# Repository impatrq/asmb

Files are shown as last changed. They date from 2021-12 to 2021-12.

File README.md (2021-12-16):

# Automatic Sanitary Modular Booth - ASMB

## ¿Que es ASMB?

ASMB es una cabina modular de desinfección automatica. El fin de esta es asegurar que un usuario se desinfecte antes de entrar en un espacio establecido, ademas de registrar su asistencia, temperatura y uso de barbijo.
Para explicación de funcionamiento en detalle, consultar el [Manual de Usuario](https://github.com/impatrq/asmb/blob/main/Docs/Carpeta%20técnica.docx)

<br>

## ¿Cuales son las bases ASMB?

- Integración: ASMB tambien cuenta con su propio sistema de registro de usuarios y estado de sensores. 

- Modularidad: Al momento de pedir sus cabinas se puede optar por cada sensor en el sistema

- Automatica: No requiere de intervención de un tercero para su utilización

<br>

## Indice

- [Documentos](https://github.com/impatrq/asmb/tree/main/Docs)

- [Historias de usuario](https://github.com/impatrq/asmb/tree/main/Historias%20de%20Usuario)

- [Live](https://github.com/impatrq/asmb/tree/main/Live)

- [Recursos](https://github.com/impatrq/asmb/tree/main/Recursos)

- [Server](https://github.com/impatrq/asmb/tree/main/Server)

## Reconocimientos
<b>2do puesto en prototipos II en Las olimpiadas nacionales ONIET</b>

<br>

## Desarollo

Juan I. Casareski: Software

Marco F. Cuccaro: Electronica

Iván Torres: Modelos

Agustín Murgia: Estructura

<br>

## Contacto

Juan I. Casareski: [juani.casareski@gmail.com](mailto:juani.casareski@gmail.com)

Marco F. Cuccaro: [cuccaromarco13@gmail.com](mailto:cuccaromarco13@gmail.com)

Iván Torres: [rantaproivo@gmail.com](mailto:rantaproivo@gmail.com)

Agustín Murgia: [murgiaagustin@gmail.com](mailto:murgiaagustin@gmail.com)

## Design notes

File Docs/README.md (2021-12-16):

||||
| :- | :-: | -: |

**Automatic Sanitary Modular Booth**



**Integrantes:**

**Casareski, Juan I.**

**Cuccaro, Marco F.**

**Murgia, Agustín N.**

**Torres, Iván B.**

**Índice:**

1. **Introducción**
   1. ** 	Objetivo del proyecto
   1. ` 	`Descripción general
   1. ` 	`Uso deseado
   1. ` 	`Diagrama en bloques
   1. ` 	`Diagrama de Gantt

2. **Componentes**
   1. ** 	Raspberry pi 4b
   1. ` 	`Sensor de temperatura infrarrojo MLX90614
   1. ` 	`Lector de tarjetas RFID RC522
   1. ` 	`Sensor de proximidad Fc-51
   1. ` 	`Sensores de reflexión E18 D80nk
   1. ` 	`Cámara USB
   1. ` 	`Shift Register 74HC595
   1. ` 	`Bomba de agua Bt30
   1. ` 	`Fuente genérica de computadora 500W

3. **Software**
   1. ** 	Clase general
   1. ` 	`Sensor de temperatura
   1. Detección facial
      1. ` 	`Detector de puntos faciales
      1. ` 	`Detector de barbijos
   1. `   	`Lector de tarjetas RFID RC522
   1. ` 	`Registro de empleados
   1. ` 	`Registro de clientes
   1. ` 	`Cartel de funcionamiento
   1. ` 	`Dispensador de alcohol en gel
   1. ` 	`Ingreso y egreso
   1. Panel de estado
   1. Funciones de día y hora

4. **Esquemáticos y PBC's**
   1. ** 	Motherboard
   1. ` 	`Panel de estado
   1. ` 	`Level shifters (Sensores de proximidad)
   1. ` 	`Adaptador RC522

5. **Modelos 3D**
   1. ` 	`Cabina completa
   1. ` 	`Soporte de la cámara
   1. ` 	`Carcasa del lector de tarjetas
   1. ` 	`Carcasa del sensor de temperatura
   1. ` 	`Dispensador de alcohol en gel

6. **Recursos**

   1. **Introducción**

1.1. **Objetivo del proyecto**

Este proyecto fue diseñado para la desinfección integral de un peatón/empleado. También cuenta con sensando de temperatura, reconocimiento facial, registro de asistencia y un indicador de funcionamiento para cada sensor. Este cuenta con un enfoque a la modularidad del sistema.

1.2 **Descripción general**

El proyecto ASMB fue construido desde la base por alumnos de la EEST N7 TRQ, cuya estructura hecha integralmente de materiales provisto en la escuela.

1.3 **Uso deseado**

La cabina está diseñada para ser montada en un espacio abierto antes del acceso a un establecimiento, donde el usuario se tomará la temperatura antes de entrar a la cabina, en caso de que sea un empleado deberá también poner su tarjeta de identificación. Una vez dentro de la cabina se le detectará la cara al usuario para determinar si tiene los ojos y boca cerrados (u opcionalmente el uso de un barbijo), una vez confirmado esto se desinfectará al usuario y este mismo podrá salir de las misma, sin antes desinfectarse las manos con el dispensador de alcohol en gel. Este mismo ingreso será guardado en una base de datos local junto a el horario de entrada, temperatura y el supuesto horario de entrada.

1.4 **Diagrama en bloques**





1.5 **Diagrama de Gantt**



2. **Componentes**

2.1 **Raspberry pi 4B**

Este microprocesador fue seleccionado ya que requeríamos de una potencia considerable para poder ejecutar los scripts de detección facial. Todas las conexiones que requieren de alguna lógica se conectan a este mediante la motherboard.

2.2 **Sensor de temperatura infrarrojo MLX90614**

El MLX90614 es un sensor de temperatura sin contacto. Este sensor tiene un error de aproximadamente 0.14 C y un rango de medición de –20 C a 120 C. Este comunica la temperatura leída al microprocesador mediante un protocolo serial I²C.

2.3 **Lector de tarjetas RFID RC522**

Este módulo lee las tarjetas RFID las cuales incluyen dos valores: id y texto. 

2.4 **Sensor de proximidad Fc-51**

Este sensor detecta objetos en su rango de visión de 15 grados, a un máximo de 30cm. Es usado en el dispensador de alcohol sin contacto.

2.5 **Sensor de reflexión E18 D80nk**

Su funcionamiento es muy similar a el sensor de proximidad (De hecho, usan el mismo concepto para cumplir su función) con la diferencia de que son más sensibles y, por lo tanto, su rango de medición máximo aumenta de 30cm a 80cm.

2.6 **Cámara USB**

La cámara seleccionada fue la sinovisión sn-u4 principalmente a que fue probada con el microprocesador al cual se le pudo instalar los drivers de la misma. A esto se le suma que cuenta con los requerimientos necesarios para nuestra aplicación.

2.7 **Shift register 74HC595**

El 74hc595 es un shift register de 8 bits, esta cuadra con nuestro uso ya que no requerimos de una alta corriente en la salida. 

2.8 **Bomba de agua Bt30**

La bomba tiene una potencia de 30W, funciona en 220W@50Hz. La mima tiene un caudal de 48L/h y una presión de 3bar, la presión de la cual requeríamos es de 2.5bar, pero tenemos un excedente principalmente debido a que el sistema puede tener perdidas.

2.9 **Fuente genérica de computadora 500W**

La fuente seleccionada fue una de computadora para mantener la simplicidad del sistema. Esta fuente se conecta a la motherboard (Ver sección 4.1.) mediante un conector molex de 24 pines.

3. **Software**

3.1 **Clase general**

Esta fue ideada para la fácil reimplementación de los pines del sistema una situación en la que esto sea de utilidad seria, por ejemplo, El reemplazo de una RP3 por otro microprocesador por una RP4 (Situación la cual se dio en el mismo proyecto). Todos los archivos están disponibles en el repositorio (Ver sección 6). 

3.2 **Sensor de temperatura**

Este sería el uso deseado de la clase <Temperatura>



El método <readTemp> devuelve dos valores, el primero hace referencia a si la persona está habilitada a entrar, siendo 'True' si se encuentra en el rango de temperatura permitido y 'False' si no se encuentra en dicho rango, el segundo valor es la temperatura leída.

3.3 **Detección Facial**

Esta parte cuenta con dos variaciones, la primera donde se detecta que los ojos y la boca estén cerrados y el segundo donde se detecta el uso de un barbijo.

3.4 **Detector de puntos faciales**	

Este se encarga de detectar el hecho de que el usuario tenga los ojos y boca cerrados por al menos 3 segundos para comenzar a desinfectar.



Cabe aclarar que al constructor <FaceDetection> se le pasa un argumento para seleccionar el modo de detección facial (En este caso 'eyes&Mouth')

3.5 **Detector de barbijos**

Este detecta de detectar el uso de un barbijo para comenzar el proceso de desinfección



La única diferencia con el ejemplo anterior es la key distinta del constructor <FaceDetection>.

3.6 **Lector de tarjetas RFID RC522**

Este lector lee los dos datos dentro de la tarjeta, primero la id y segundo el text. El ejemplo siguiente lee estos dos anteriormente nombrados.



3.6 **Registro de empleados**

El registro de empleados se implementó mediante una función la cual pide con parámetros la id de este trabajador y su temperatura, esta misma función se encarga de conseguir la hora y día actual y de guardarlo todos los datos en una base de datos local.



En este ejemplo primero se le toma la temperatura al empleado, después su tarjeta de identificación y se guarda en la base de datos. Cabe aclarar que tanto el id de la tarjeta como el estado del sensor de temperatura no se utilizan en este ejemplo por lo que se les reemplazó por una '\_'.

3.7 **Registro de clientes**

El registro de empleados es una versión simplificada del registro de empleados, ya que un peatón normal no cuenta con una tarjeta de identificación por lo que no se ve sometido a un paso extra.



3.8 **Cartel de funcionamiento**

El fin de este cartel es de indicar cuando la cabina está fuera de funcionamiento o cuando está ocupada. 



Este ejemplo alterna el estado del panel de funcionamiento cada .5 segundos. Cabe aclarar que en la línea 5 el constructor <Pin> requiere 3 argumentos: el primero es el número de pin, el segundo es su modo de funcionamiento y el tercero es el estado inicial de dicho pin.

3.9 **Dispensador de alcohol en gel**

El dispensador de alcohol tiene la particularidad que tiene que funcionar de forma independiente al resto del sistema. Por esto utilizamos el módulo <threading>. Ignorando ese hecho el sistema lee un pin donde se conecta el sensor de proximidad para dispensar el alcohol.



Como se puede observar en el ejemplo primero se crea los objetos para los pines del sensor de proximidad y del motor, los cuales se pasan como argumento a el constructor <DispenserAlcohol>, constructor el cual toma 3 argumentos, siendo el tercero el tiempo total de activación del motor. Finalmente se crea un hilo el cual ejecuta el método principal del dispensador de alcohol.

3.10 **Ingreso y egreso**

La sección de ingreso y egreso se refiere a los sensores de proximidad que se encargan de lo anterior nombrado. La lógica detrás de este proceso es esperar hasta que algo corte el haz del sensor y el microprocesador lo lea.



En este ejemplo primero se definen los pines de los sensores de proximidad y de un led de debug (Que indica que una persona está en la cabina) y estos pines se dan como argumentos al constructor <IO>. Finalmente se verifica hasta que alguien pase por enfrente del sensor de proximidad de la entrada y posteriormente con el de la salida. 

3.11 **Panel de estado**

El estado de los sensores se manda mediante una comunicación serial sincrónica hacia un shift register (Ver sección 4.2.). El microprocesador comunica 1 byte de datos, en el cual cada bit indica si x sensor tiene una falla.



En el ejemplo anterior primero se crea el objeto del cartel de funcionamiento (Ver sección 3.7.), posteriormente se definen los pines del clock de los registros del shift register, el pin de datos y el pin de clock de la salida del shift register (Sh\_cp, ds y St\_cp, respectivamente). Después se definen los pines de entrada de los sensores de efecto hall. Finalmente crea el objeto del panel de estado con base el constructor <PanelEstado> y se lee el estado de todos los sensores, para posteriormente mostrarlos en el panel de estado.

3.12 **Funciones de día y hora**

Esta sección hace referencia a un set de funciones escritas para estandarizar la obtención de hora/día/día de la semana dentro del proyecto. Estas utilizan el módulo <datetime> para su funcionalidad.



4 **Esquemáticos y PBC's**  

   4.1 **Motherboard**

El fin este circuito es de conectar todos los dispositivos periféricos al microprocesador. 





4.2 **Panel de estado**

Este panel recibe el estado de todos los sensores desde el microprocesador y lo indica en 8 LED's. Esta señal se recibe como un paquete de 1 byte, el cual indica este en 8 LED's distintos mediante un 74HC595, a la salida de cada registro del anterior nombrad hay un BC337 ya que la corriente máxima soportada por el shift register es facilmente excedida por un par de LED's prendidos.





4.3 **Level shifters**

Este circuito es el encargado de adaptar los niveles lógicos de los sensores de efecto hall y de los sensores de proximidad y reflexión. Los anteriores nombrados usan 5v para representar un 1 lógico, este circuito es el encargado de convertir estos 5v a 3v3, mediante un diodo Zener.





4.4 **Adaptador RC522**

Este circuito tiene la única y sola función de adaptar la tira de pines del RC522 a unas borneras para su fácil conexión. 





1. **Modelos 3D**

Todos los modelos están disponibles en el repositorio del proyecto (Ver sección 6), en el directorio src>Recursos>Modelos

1. **Cabina completa**



1. **Soporte de la cámara**



1. **Carcasa del lector de tarjetas**



1. **Carcasa del sensor de temperatura**



1. **Dispensador de alcohol en gel**



6. **Recursos**

[**Modelos 3D**](https://github.com/impatrq/asmb/tree/main/Recursos/Modelos)

[**Circuitos y PCB's**](https://github.com/impatrq/asmb/tree/main/Recursos/Circuitos)

[**Script**](https://github.com/impatrq/asmb/tree/main/Live/src/Libs)

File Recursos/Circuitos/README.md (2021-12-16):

<font size="8">CIRCUITOS:

<font size="3">
 Estos son los circuitos que van a encontrar en esta seccion:

<font size="4">

[Circuito del dispenser:](https://github.com/impatrq/asmb/blob/main/Recursos/Circuitos/Dispenser%20de%20alcohol/Dispenser%20de%20alcohol%20en%20gel.pdsprj)



[Circuito del lector de tarjetas:](https://github.com/impatrq/asmb/blob/main/Recursos/Circuitos/Lector%20de%20tarjetas/Lector%20de%20tarjetas.pdsprj)



[Circuito de la mother:](https://github.com/impatrq/asmb/blob/main/Recursos/Circuitos/Mother/Mother.pdsprj)



[Circuito del panel de estado:](https://github.com/impatrq/asmb/blob/main/Recursos/Circuitos/Panel%20de%20estado/Panel%20de%20estado.pdsprj)



[Circuito de los sensores de proximidad:](https://github.com/impatrq/asmb/blob/main/Recursos/Circuitos/Proximity%20sensors/Level%20adapter.pdsprj)



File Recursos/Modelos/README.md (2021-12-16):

[Modelo de la cabina:](https://github.com/impatrq/asmb/blob/main/Recursos/Modelos/Cabina%20general/Modelo%20Cabina.dwg)



[Modelo del cartel de ocupado:](https://github.com/impatrq/asmb/blob/main/Recursos/Modelos/Cartel%20ocupado/Cartel%20Ocupado.dwg)



[Dispenser de alcohol:](https://github.com/impatrq/asmb/blob/main/Recursos/Modelos/Dispenser%20de%20alcohol%20en%20gel/Dispenser%20de%20alcohol%20en%20gel.dwg)



[Lector de tarjetas:](https://github.com/impatrq/asmb/blob/main/Recursos/Modelos/Dispenser%20de%20alcohol%20en%20gel/Dispenser%20de%20alcohol%20en%20gel.dwg)



[Sensor de temperatura:](https://github.com/impatrq/asmb/blob/main/Recursos/Modelos/Sensor%20de%20temperatura/Sensor%20de%20temperatura.dwg)



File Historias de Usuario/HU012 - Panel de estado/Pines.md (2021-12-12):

# Pines

* **Lector de tarjetas**        [GPIO19, GPIO16, GPIO20, GPIO21] **SPI1**
* **Sensor de temperatura**     [GPIO2, GPIO3] **I²C1** 
* **Sensores de obstaculos**    [GPIO18, GPIO23, GPIO24, GPIO25, GPIO8, GPIO7]
* **Buzzer**                    [GPIO12]
* **Pin testeo LEDS**           [GPIO4]
* **Pines del panel de estado** [GPIO17, GPIO27, GPIO22]

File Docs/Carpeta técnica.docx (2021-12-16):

Automatic Sanitary Modular Booth

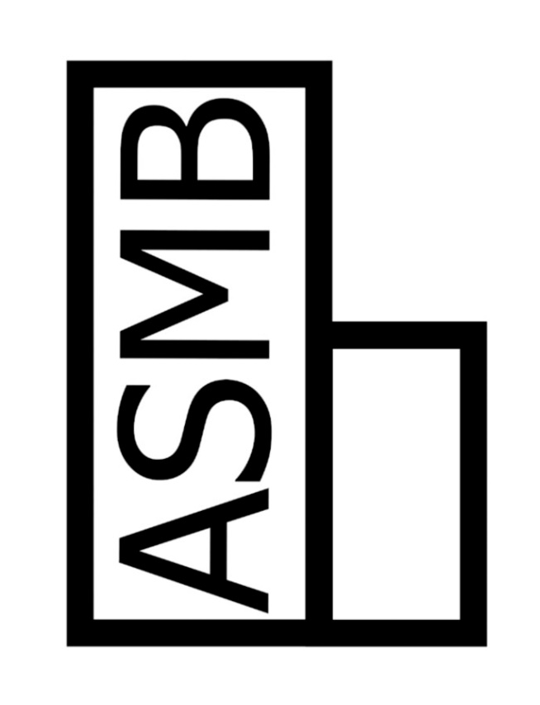
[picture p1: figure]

Integrantes:

Casareski, Juan I.

Cuccaro, Marco F.

Murgia, Agustín N.

Torres, Iván B.

Índice:

1. Introducción
  1.1. Objetivo del proyecto
  1.2. Descripción general
  1.3. Uso deseado
  1.4. Diagrama en bloques
  1.5. Diagrama de Gantt
2. Componentes
  2.1. Raspberry pi 4b
  2.2. Sensor de temperatura infrarrojo MLX90614
  2.3. Lector de tarjetas RFID RC522
  2.4. Sensor de proximidad Fc-51
  2.5. Sensores de reflexión E18 D80nk
  2.6. Cámara USB
  2.7. Shift Register 74HC595
  2.8. Bomba de agua Bt30
  2.9. Fuente genérica de computadora 500W
3. Software
  3.1. Clase general
  3.2. Sensor de temperatura
  3.3. Detección facial
    3.3.1. Detector de puntos faciales
    3.3.2. Detector de barbijos
  3.4. Lector de tarjetas RFID RC522
  3.5. Registro de empleados
  3.6. Registro de clientes
  3.7. Cartel de funcionamiento
  3.8. Dispensador de alcohol en gel
  3.9. Ingreso y egreso
  3.10. Panel de estado
  3.11. Funciones de día y hora
4. Esquemáticos y PBC's
  4.1. Motherboard
  4.2. Panel de estado
  4.3. Level shifters (Sensores de proximidad)
  4.4. Adaptador RC522
5. Modelos 3D
  5.1. Cabina completa
  5.2. Soporte de la cámara
  5.3. Carcasa del lector de tarjetas
  5.4. Carcasa del sensor de temperatura
  5.5. Dispensador de alcohol en gel
6. Recursos
1. Introducción
  1.1. Objetivo del proyecto

Este proyecto fue diseñado para la desinfección integral de un peatón/empleado. También cuenta con sensando de temperatura, reconocimiento facial, registro de asistencia y un indicador de funcionamiento para cada sensor. Este cuenta con un enfoque a la modularidad del sistema.

  1.2. Descripción general

El proyecto ASMB fue construido desde la base por alumnos de la EEST N7 TRQ, cuya estructura hecha integralmente de materiales provisto en la escuela.

  1.3. Uso deseado

La cabina está diseñada para ser montada en un espacio abierto antes del acceso a un establecimiento, donde el usuario se tomará la temperatura antes de entrar a la cabina, en caso de que sea un empleado deberá también poner su tarjeta de identificación. Una vez dentro de la cabina se le detectará la cara al usuario para determinar si tiene los ojos y boca cerrados (u opcionalmente el uso de un barbijo), una vez confirmado esto se desinfectará al usuario y este mismo podrá salir de las misma, sin antes desinfectarse las manos con el dispensador de alcohol en gel. Este mismo ingreso será guardado en una base de datos local junto a el horario de entrada, temperatura y el supuesto horario de entrada.

  1.4. Diagrama en bloques

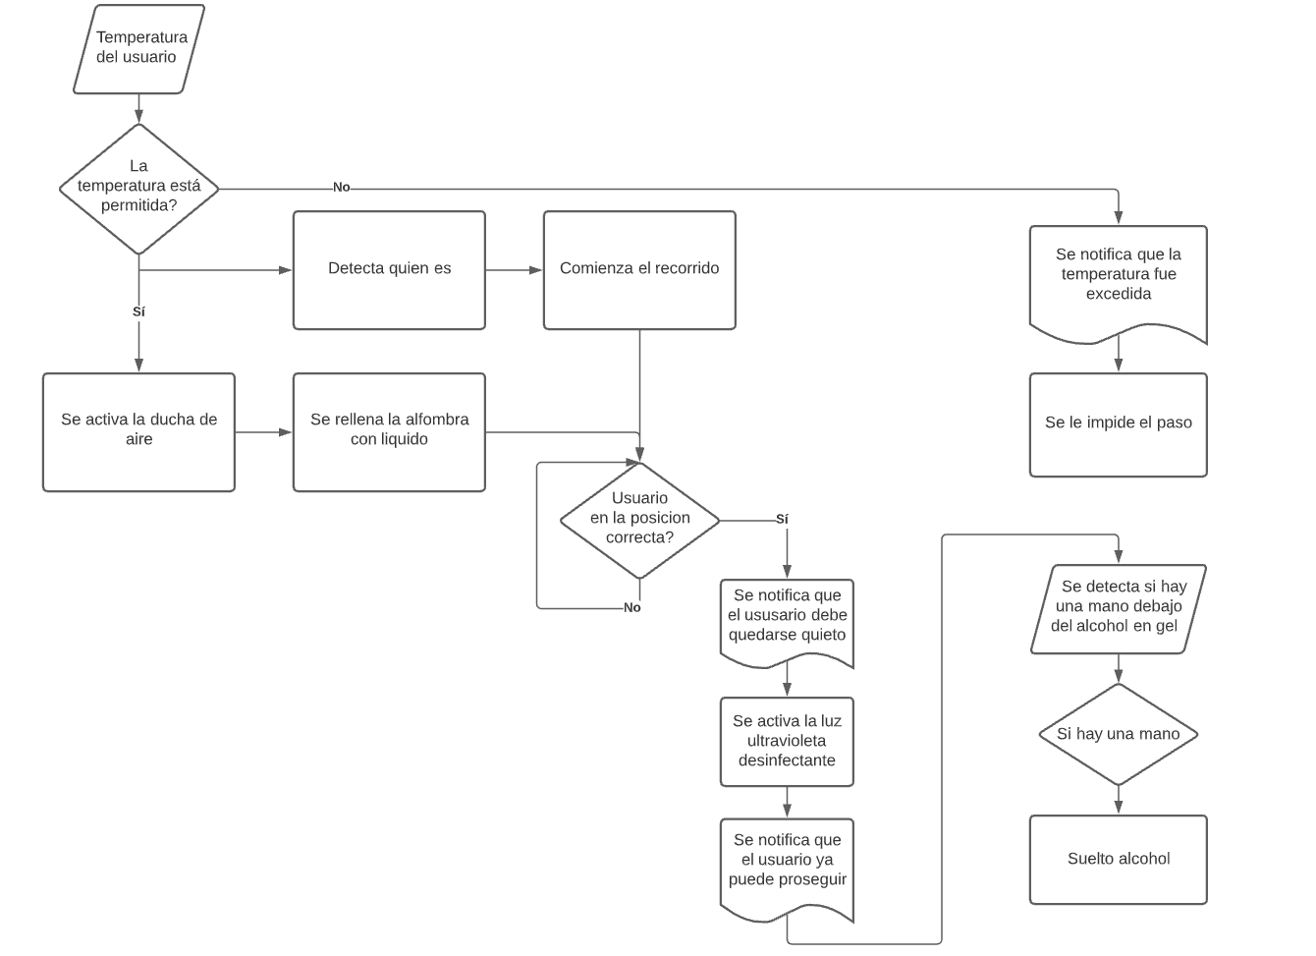
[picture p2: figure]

  1.5. Diagrama de Gantt

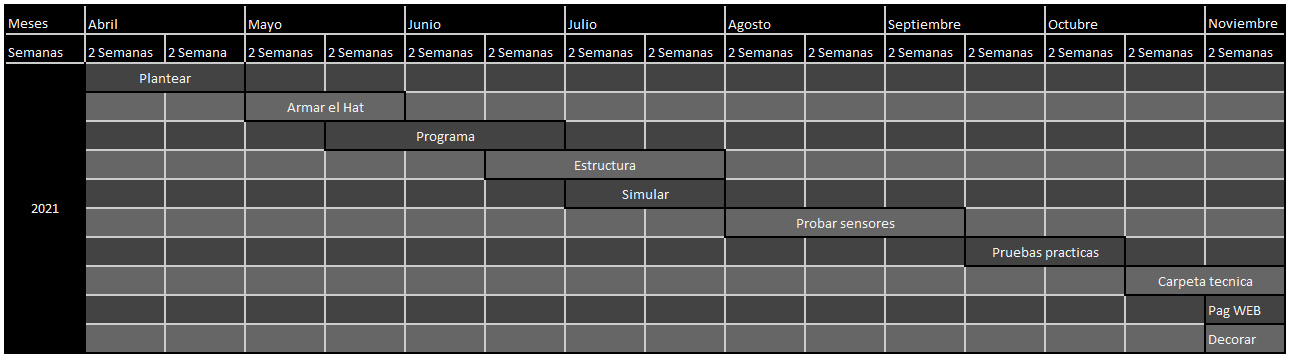
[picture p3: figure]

2. Componentes
  2.1. Raspberry pi 4B

Este microprocesador fue seleccionado ya que requeríamos de una potencia considerable para poder ejecutar los scripts de detección facial. Todas las conexiones que requieren de alguna lógica se conectan a este mediante la motherboard.

  2.2. Sensor de temperatura infrarrojo MLX90614

El MLX90614 es un sensor de temperatura sin contacto. Este sensor tiene un error de aproximadamente 0.14 C y un rango de medición de –20 C a 120 C. Este comunica la temperatura leída al microprocesador mediante un protocolo serial I²C.

  2.3. Lector de tarjetas RFID RC522

Este módulo lee las tarjetas RFID las cuales incluyen dos valores: id y texto.

  2.4. Sensor de proximidad Fc-51

Este sensor detecta objetos en su rango de visión de 15 grados, a un máximo de 30cm. Es usado en el dispensador de alcohol sin contacto.

  2.5. Sensor de reflexión E18 D80nk

Su funcionamiento es muy similar a el sensor de proximidad (De hecho, usan el mismo concepto para cumplir su función) con la diferencia de que son más sensibles y, por lo tanto, su rango de medición máximo aumenta de 30cm a 80cm.

  2.6. Cámara USB

La cámara seleccionada fue la sinovisión sn-u4 principalmente a que fue probada con el microprocesador al cual se le pudo instalar los drivers de la misma. A esto se le suma que cuenta con los requerimientos necesarios para nuestra aplicación.

  2.7. Shift register 74HC595

El 74hc595 es un shift register de 8 bits, esta cuadra con nuestro uso ya que no requerimos de una alta corriente en la salida.

  2.8. Bomba de agua Bt30

La bomba tiene una potencia de 30W, funciona en 220W@50Hz. La mima tiene un caudal de 48L/h y una presión de 3bar, la presión de la cual requeríamos es de 2.5bar, pero tenemos un excedente principalmente debido a que el sistema puede tener perdidas.

  2.9. Fuente genérica de computadora 500W

La fuente seleccionada fue una de computadora para mantener la simplicidad del sistema. Esta fuente se conecta a la motherboard (Ver sección 4.1.) mediante un conector molex de 24 pines.

3. Software
  3.1. Clase general

Esta fue ideada para la fácil reimplementación de los pines del sistema una situación en la que esto sea de utilidad seria, por ejemplo, El reemplazo de una RP3 por otro microprocesador por una RP4 (Situación la cual se dio en el mismo proyecto). Todos los archivos están disponibles en el repositorio (Ver sección 6).

  3.2. Sensor de temperatura

Este sería el uso deseado de la clase <Temperatura>

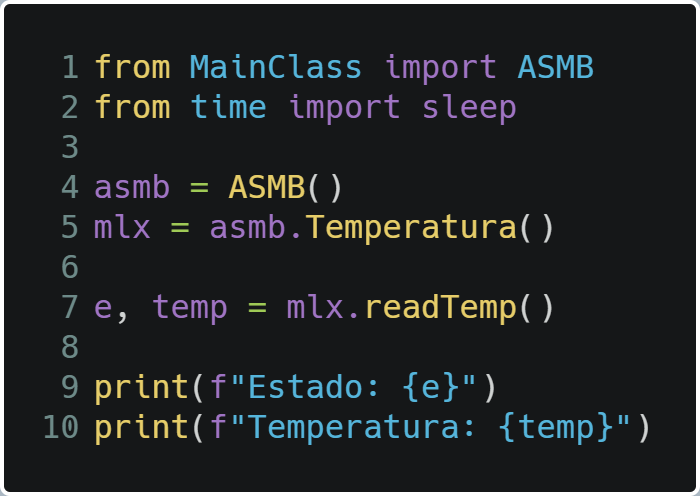
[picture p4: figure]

El método <readTemp> devuelve dos valores, el primero hace referencia a si la persona está habilitada a entrar, siendo 'True' si se encuentra en el rango de temperatura permitido y 'False' si no se encuentra en dicho rango, el segundo valor es la temperatura leída.

  3.3. Detección Facial

Esta parte cuenta con dos variaciones, la primera donde se detecta que los ojos y la boca estén cerrados y el segundo donde se detecta el uso de un barbijo.

    3.3. Detector de puntos faciales

Este se encarga de detectar el hecho de que el usuario tenga los ojos y boca cerrados por al menos 3 segundos para comenzar a desinfectar.

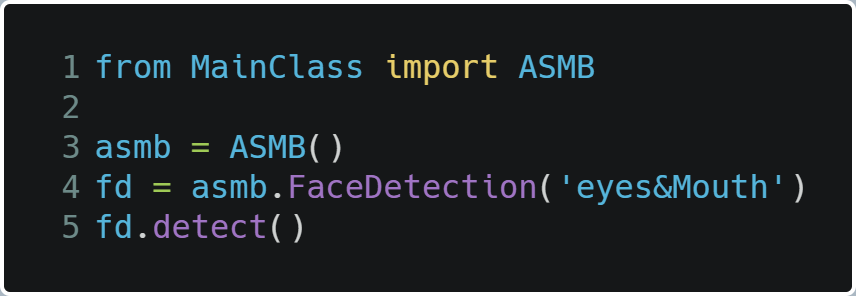
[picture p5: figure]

Cabe aclarar que al constructor <FaceDetection> se le pasa un argumento para seleccionar el modo de detección facial (En este caso 'eyes&Mouth')

    3.3. Detector de barbijos

Este detecta de detectar el uso de un barbijo para comenzar el proceso de desinfección

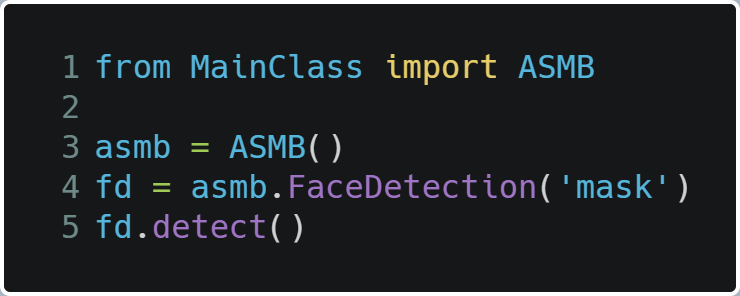
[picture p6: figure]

La única diferencia con el ejemplo anterior es la key distinta del constructor <FaceDetection>.

  3.4. Lector de tarjetas RFID RC522

Este lector lee los dos datos dentro de la tarjeta, primero la id y segundo el text. El ejemplo siguiente lee estos dos anteriormente nombrados.

  3.5. Registro de empleados

El registro de empleados se implementó mediante una función la cual pide con parámetros la id de este trabajador y su temperatura, esta misma función se encarga de conseguir la hora y día actual y de guardarlo todos los datos en una base de datos local.

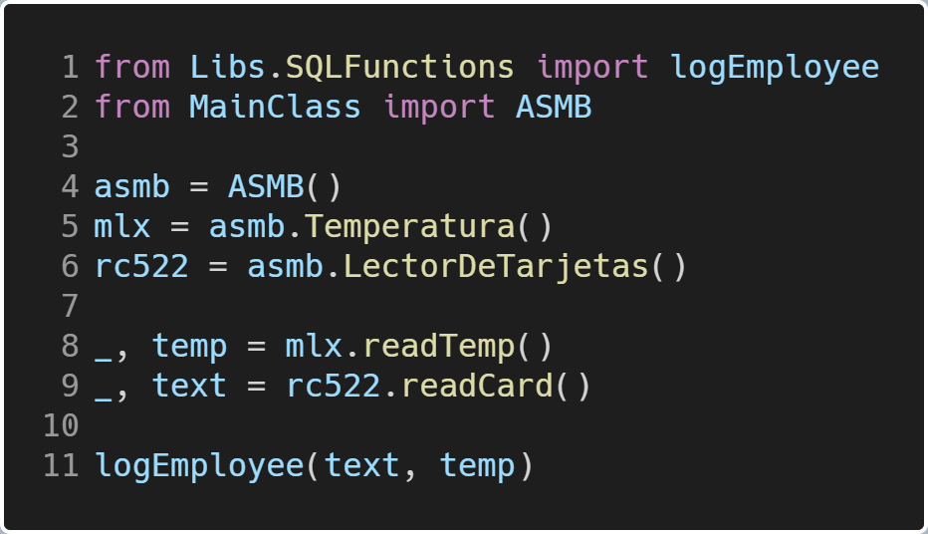
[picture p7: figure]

En este ejemplo primero se le toma la temperatura al empleado, después su tarjeta de identificación y se guarda en la base de datos. Cabe aclarar que tanto el id de la tarjeta como el estado del sensor de temperatura no se utilizan en este ejemplo por lo que se les reemplazó por una '_'.

  3.6. Registro de clientes

El registro de empleados es una versión simplificada del registro de empleados, ya que un peatón normal no cuenta con una tarjeta de identificación por lo que no se ve sometido a un paso extra.

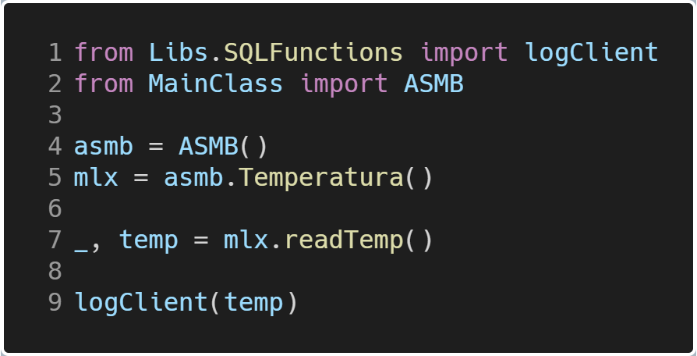
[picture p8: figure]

  3.7. Cartel de funcionamiento

El fin de este cartel es de indicar cuando la cabina está fuera de funcionamiento o cuando está ocupada.

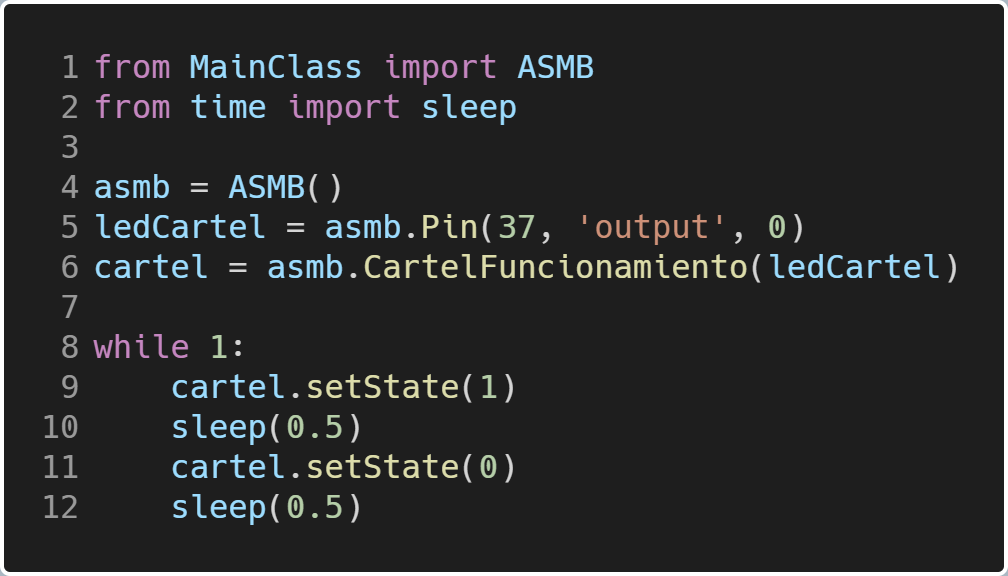
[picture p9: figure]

Este ejemplo alterna el estado del panel de funcionamiento cada .5 segundos. Cabe aclarar que en la línea 5 el constructor <Pin> requiere 3 argumentos: el primero es el número de pin, el segundo es su modo de funcionamiento y el tercero es el estado inicial de dicho pin.

  3.8. Dispensador de alcohol en gel

El dispensador de alcohol tiene la particularidad que tiene que funcionar de forma independiente al resto del sistema. Por esto utilizamos el módulo <threading>. Ignorando ese hecho el sistema lee un pin donde se conecta el sensor de proximidad para dispensar el alcohol.

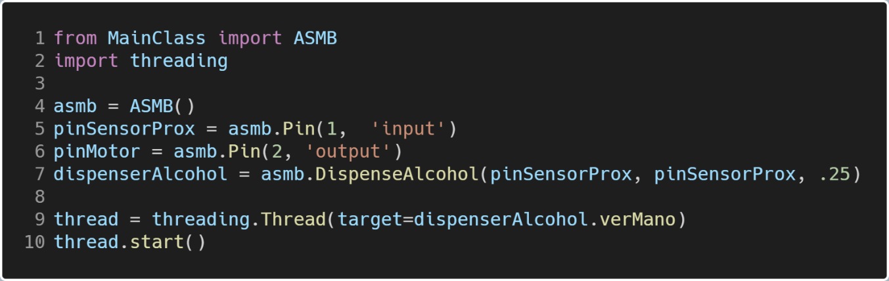
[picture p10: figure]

Como se puede observar en el ejemplo primero se crea los objetos para los pines del sensor de proximidad y del motor, los cuales se pasan como argumento a el constructor <DispenserAlcohol>, constructor el cual toma 3 argumentos, siendo el tercero el tiempo total de activación del motor. Finalmente se crea un hilo el cual ejecuta el método principal del dispensador de alcohol.

  3.9. Ingreso y egreso

La sección de ingreso y egreso se refiere a los sensores de proximidad que se encargan de lo anterior nombrado. La lógica detrás de este proceso es esperar hasta que algo corte el haz del sensor y el microprocesador lo lea.

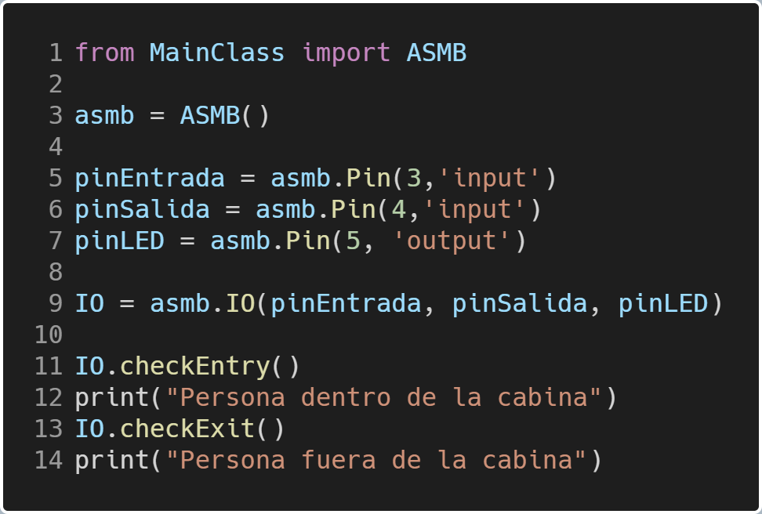
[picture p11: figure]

En este ejemplo primero se definen los pines de los sensores de proximidad y de un led de debug (Que indica que una persona está en la cabina) y estos pines se dan como argumentos al constructor <IO>. Finalmente se verifica hasta que alguien pase por enfrente del sensor de proximidad de la entrada y posteriormente con el de la salida.

  3.10. Panel de estado

El estado de los sensores se manda mediante una comunicación serial sincrónica hacia un shift register (Ver sección 4.2.). El microprocesador comunica 1 byte de datos, en el cual cada bit indica si x sensor tiene una falla.

En el ejemplo anterior primero se crea el objeto del cartel de funcionamiento (Ver sección 3.7.), posteriormente se definen los pines del clock de los registros del shift register, el pin de datos y el pin de clock de la salida del shift register (Sh_cp, ds y St_cp, respectivamente). Después se definen los pines de entrada de los sensores de efecto hall. Finalmente crea el objeto del panel de estado con base el constructor <PanelEstado> y se lee el estado de todos los sensores, para posteriormente mostrarlos en el panel de estado.

  3.11. Funciones de día y hora

Esta sección hace referencia a un set de funciones escritas para estandarizar la obtención de hora/día/día de la semana dentro del proyecto. Estas utilizan el módulo <datetime> para su funcionalidad.

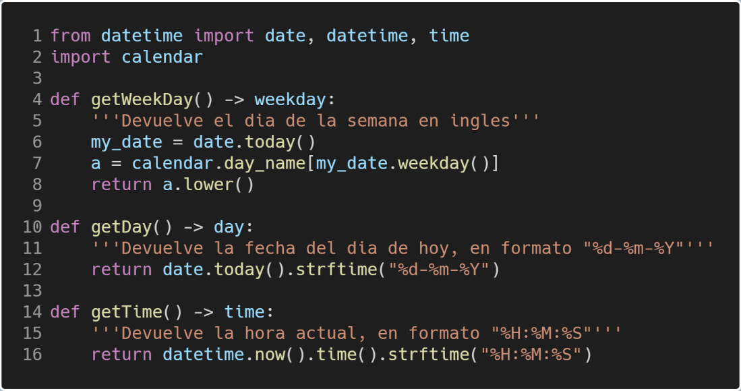
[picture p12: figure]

4. Esquemáticos y PBC's
  4.1. Motherboard

El fin este circuito es de conectar todos los dispositivos periféricos al microprocesador.

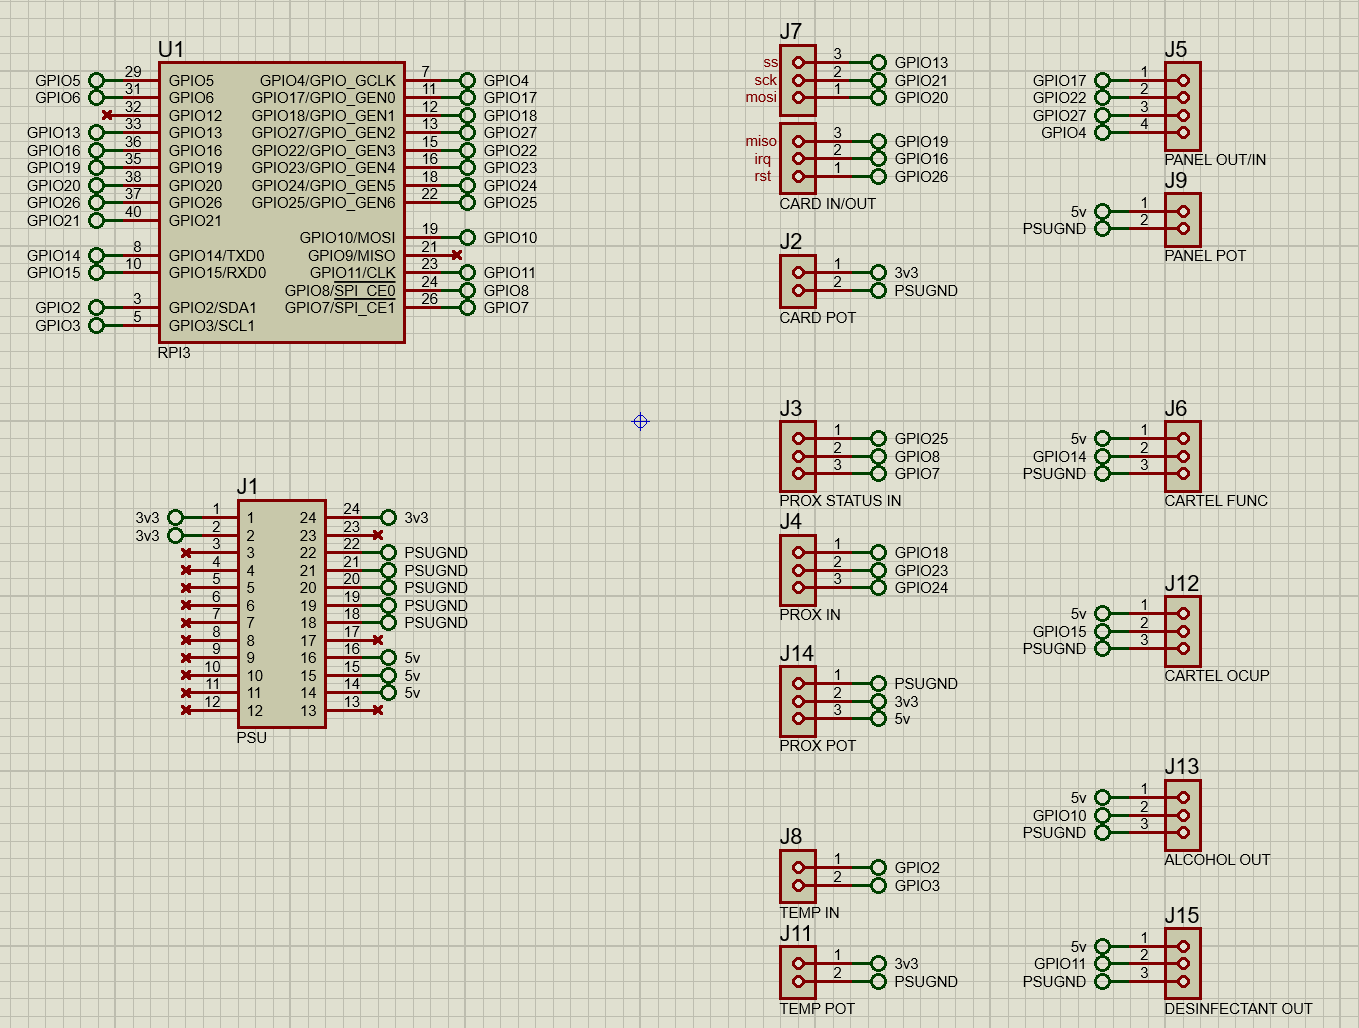
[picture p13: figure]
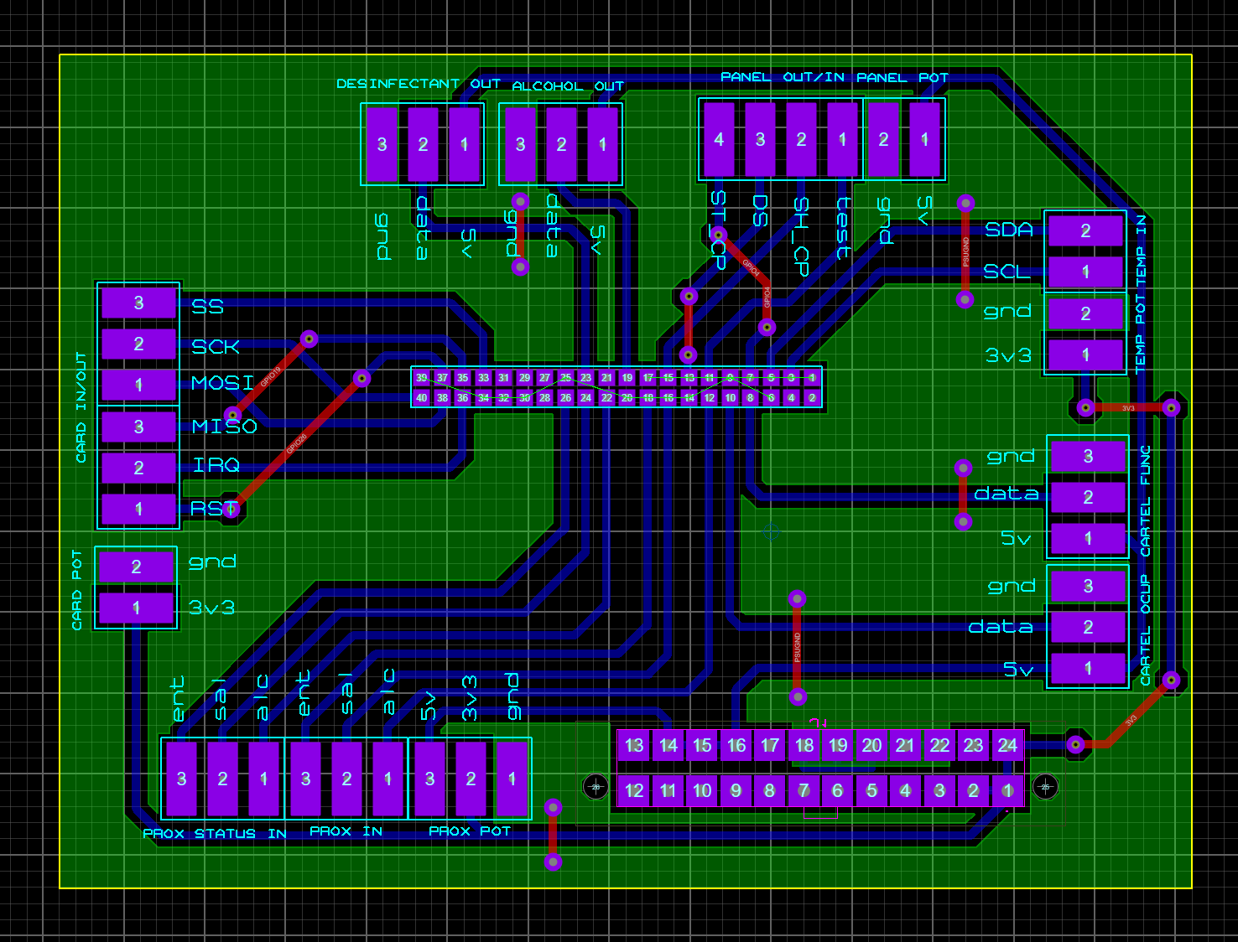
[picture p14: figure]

  4.2. Panel de estado

Este panel recibe el estado de todos los sensores desde el microprocesador y lo indica en 8 LED's. Esta señal se recibe como un paquete de 1 byte, el cual indica este en 8 LED's distintos mediante un 74HC595, a la salida de cada registro del anterior nombrad hay un BC337 ya que la corriente máxima soportada por el shift register es facilmente excedida por un par de LED's prendidos.

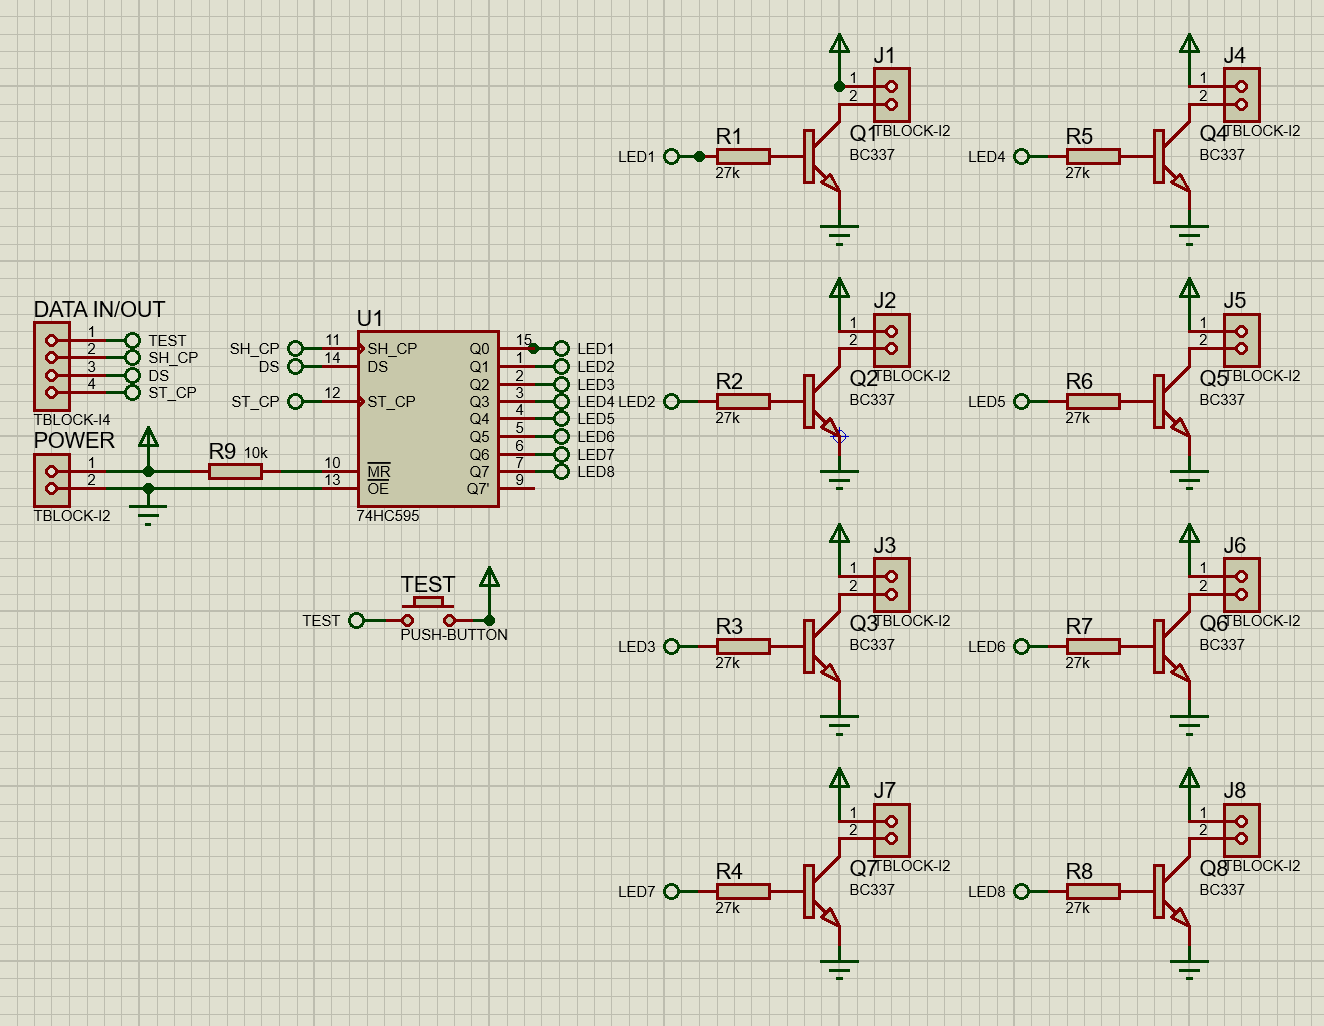
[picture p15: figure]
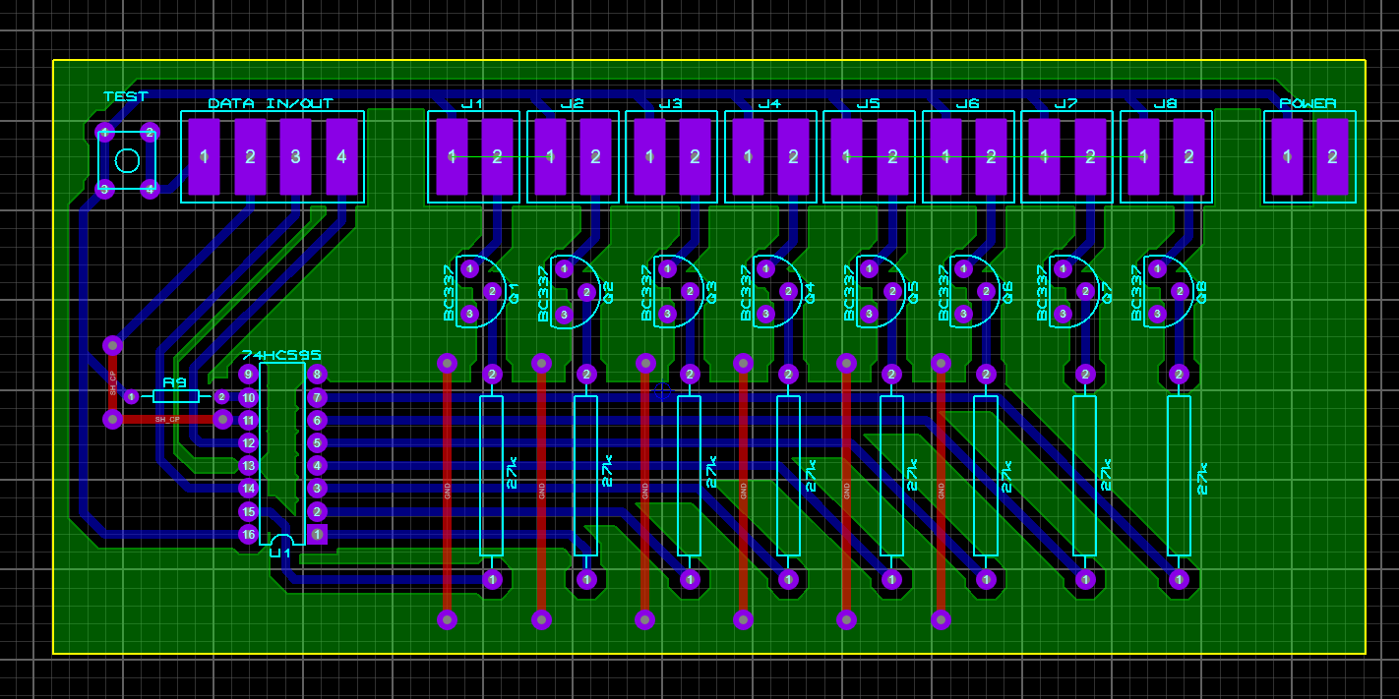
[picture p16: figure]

  4.3. Level shifters

Este circuito es el encargado de adaptar los niveles lógicos de los sensores de efecto hall y de los sensores de proximidad y reflexión. Los anteriores nombrados usan 5v para representar un 1 lógico, este circuito es el encargado de convertir estos 5v a 3v3, mediante un diodo Zener.

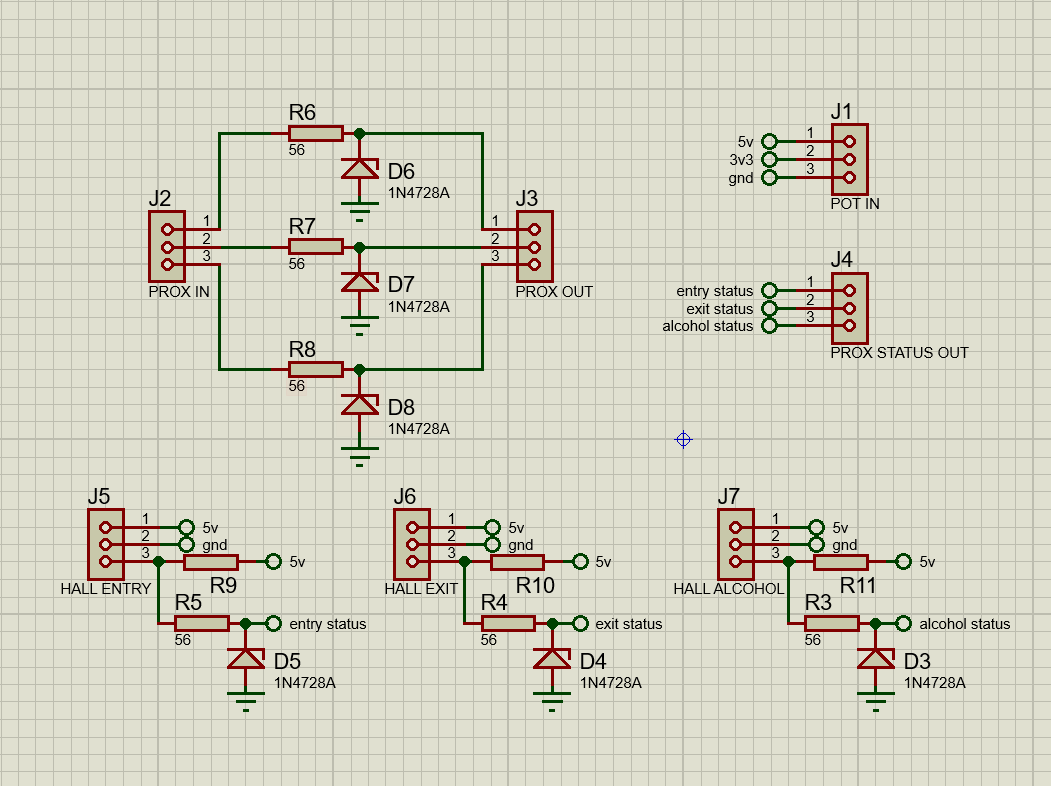
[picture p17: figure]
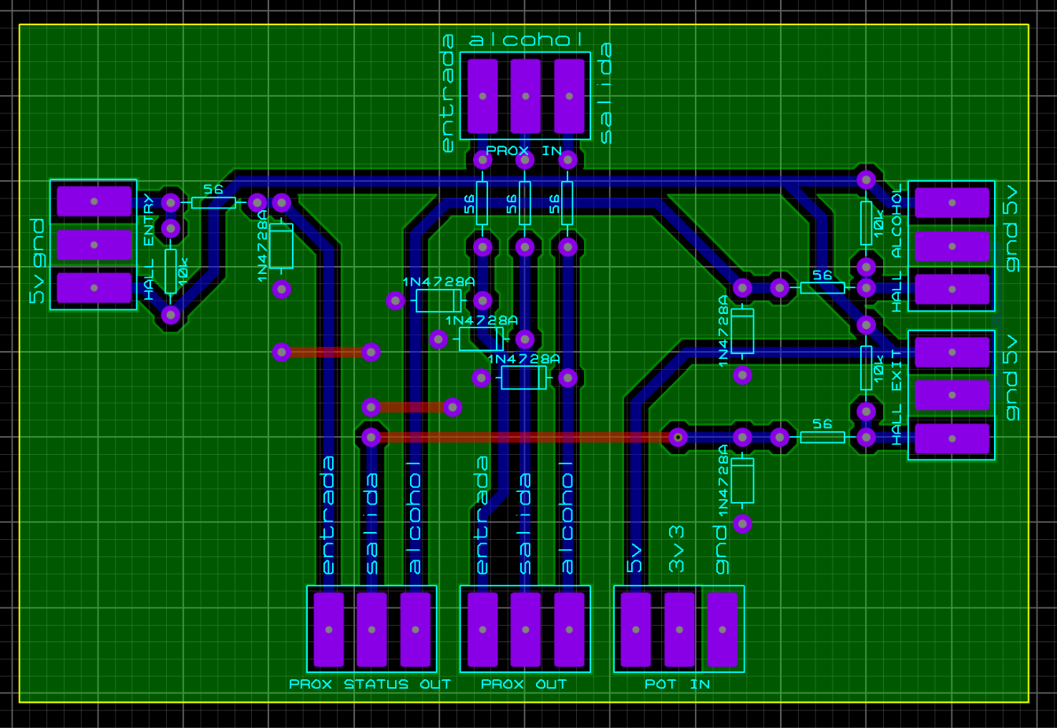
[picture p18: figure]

  4.4. Adaptador RC522

Este circuito tiene la única y sola función de adaptar la tira de pines del RC522 a unas borneras para su fácil conexión.

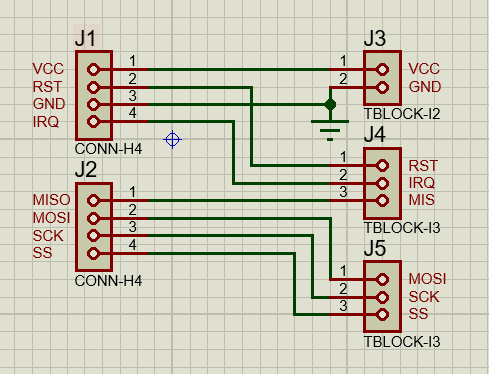
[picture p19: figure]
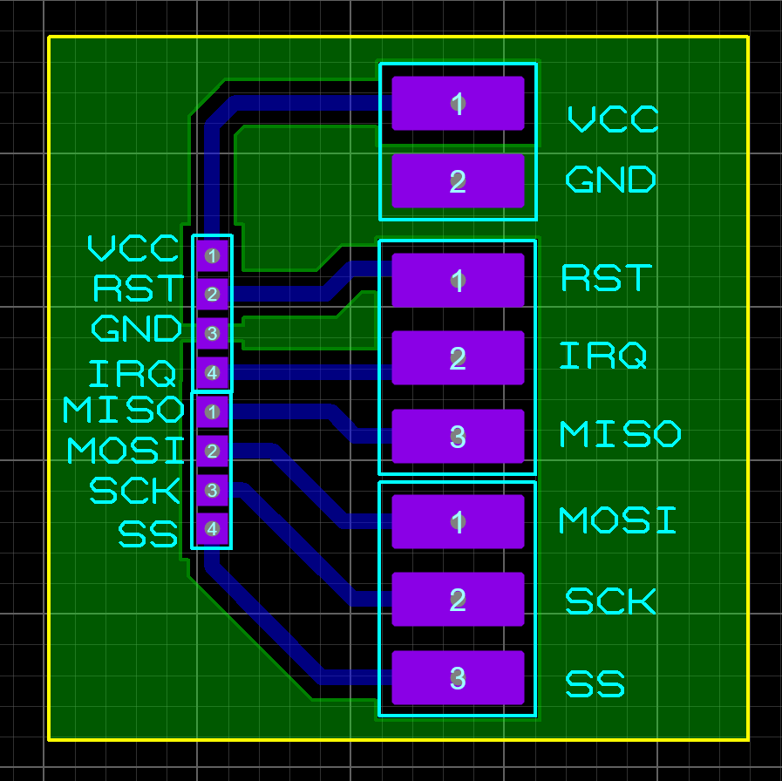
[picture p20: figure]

5. Modelos 3D

Todos los modelos están disponibles en el repositorio del proyecto (Ver sección 6), en el directorio src>Recursos>Modelos

  5.1. Cabina completa

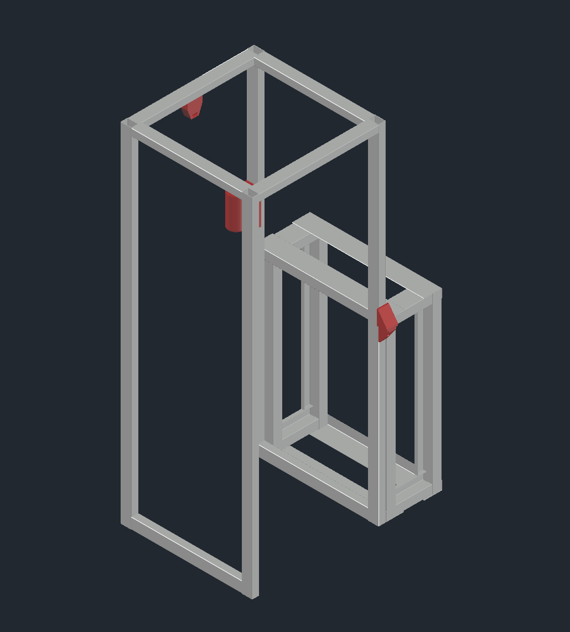
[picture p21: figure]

  5.2. Soporte de la cámara

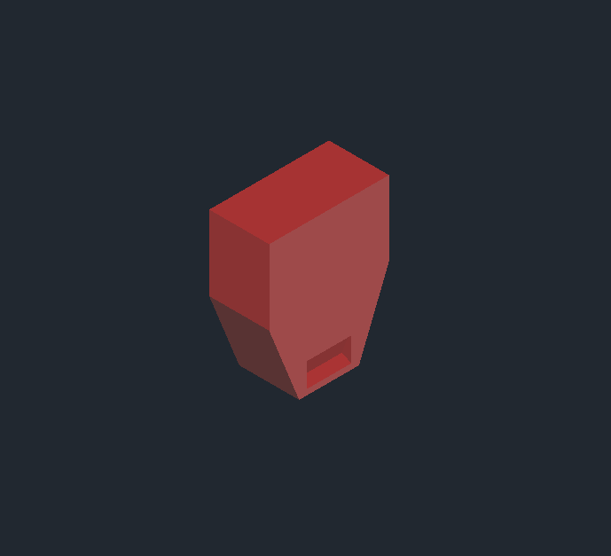
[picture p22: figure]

  5.3. Carcasa del lector de tarjetas
  5.4. Carcasa del sensor de temperatura

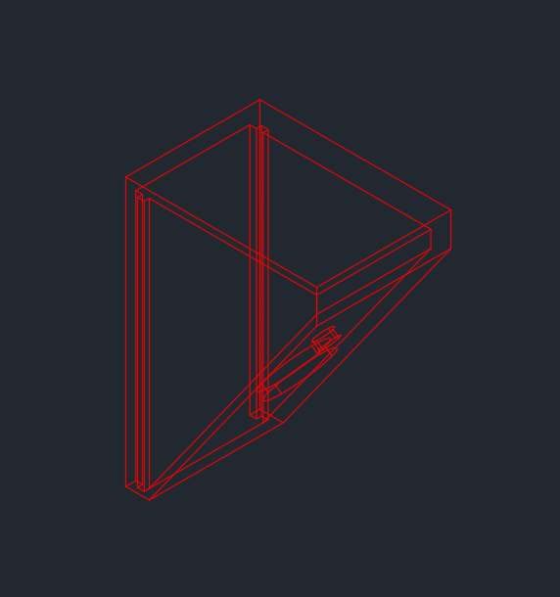
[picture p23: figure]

  5.5. Dispensador de alcohol en gel

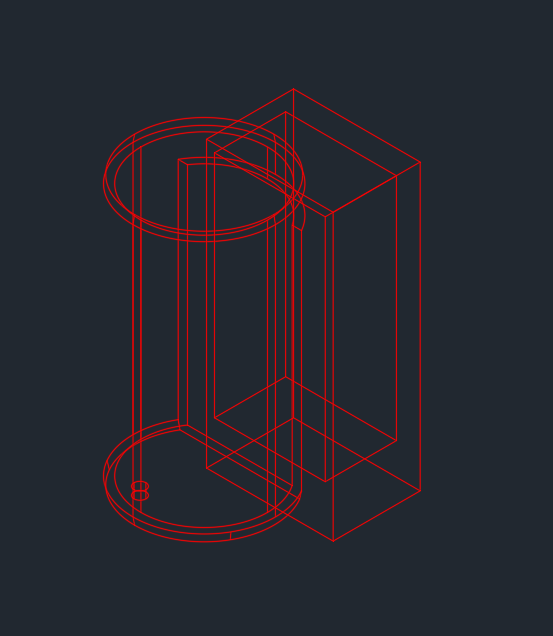
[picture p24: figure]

6. Recursos

Modelos 3D (https://github.com/impatrq/asmb/tree/main/Recursos/Modelos)

Circuitos y PCB's (https://github.com/impatrq/asmb/tree/main/Recursos/Circuitos)

Software (https://github.com/impatrq/asmb/tree/main/Live/src/Libs)

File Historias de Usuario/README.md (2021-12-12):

# Historias de usuario para ASMB
Nota: No todas las HU y reuniones diarias se encuentran aquí debido a un cambio de modalidad. Ver ramas y carpeta de campo, correspondientemente.

## Nomenclatura
### HUx01 - *Nombre*
* El primer numero seria la version de las historias de usuario.
* El segundo y tercer numero seria el numeor de historia de usuario.

## Links:
* [Preproyecto](https://docs.google.com/document/d/1FV1TCATaDeYYaNmAFFsy11UKM_EqK5jApIGANrdqngo/edit)
* [Backlog](https://docs.google.com/document/d/16Rr1VwQktRlqgh4Xqv46rgp91BMWeoB3IwLuBnragbY/edit#heading=h.weea1lfqqklc)
* [Kanban](https://trello.com/b/mIzg2lCd/kanban)
* [Presupuesto](https://docs.google.com/spreadsheets/d/1yRdK-Eko-lI7sWNFI4KGX0eHRzDyLPdNAgaI6_2Puz0/edit#gid=1138026163) 
* [Carpeta de campo](https://docs.google.com/document/d/14BjXpj9pFJPTAwgjcMGalzsc1YWqpey3uLjJZyRDOYk/edit)

##  Reuniones diarias
* [Numero 1](https://docs.google.com/document/d/1fbjTVGKN6UK2ypsj58MigzDZBV4JqDfpoNBA260o19w/edit)
* [Numero 2](https://docs.google.com/document/d/1secXsdiJPvNKDajAuvaiqy5pPPDZEDYqaAkMTPRFNbI/edit#heading=h.h71roo2449rv)
* [Numero 3](https://docs.google.com/document/d/1qsJ3fDMQgtzN63gmlJDIWsVr7Tw8ezWjJhJc95xvuNA/edit#heading=h.h71roo2449rv)
* [Numero 4](https://docs.google.com/document/d/1KNzdN_EXZSQ-V1OU6cUcHMQz983kYVmnH7aCcEXO-eM/edit)
* [Numero 5](https://docs.google.com/document/d/1U1-GtIy4eILVBWWnxCPecTvAWEhObhNTP5klEZfFRpc/edit#heading=h.h71roo2449rv)
* [Numero 6](https://docs.google.com/document/d/1Cb8OvNoc9IPj2QRsgWuGSvLevpwnQiieEr6IIpKQLSA/edit#heading=h.s33p57rujo5s)
* [Numero 7](https://docs.google.com/document/d/1HMkjGyC2qab5WeuxTljDNFJyogPWixypNVS3iUwOfi4/edit)  
* [Numero 8](https://docs.google.com/document/d/1qp6OVcNjNDc6ESG3M3FEdfnKejqKzGu85QJH8a0bdiE/edit)
* [Numero 9](https://docs.google.com/document/d/1tMuqNxIj3RjBa2gOgdUN-t-b4i-DhyNBBJgICMQvAsI/edit#heading=h.h71roo2449rv)
* [Numero 10](https://docs.google.com/document/d/1AkDY9smrYE4cBNo1F4DwCtP-yqBBLF-RQazNz6R8zXU/edit#)
* [Numero 11](https://docs.google.com/document/d/1fDhV-t1zMMQQbjkvNoJgaVOeUbKaTyVPhqJIyArqNPM/edit#heading=h.h71roo2449rv)
* [Numero 12](https://docs.google.com/document/d/1300NjhCsmu4e-LdjKrJJlq85LFgbSNkftzQpp0MV8FI/edit)
* [Numero 13](https://docs.google.com/document/d/1oHg5pG2QIQaJizJspj-Y5EcBHvdb56QZa5SRq5MTqro/edit)
* [Numero 14](https://docs.google.com/document/d/109d6mssrxLfDujirHsA-t52z4BgiwEK4uZniW0Y0910/edit)
* [Numero 15](https://docs.google.com/document/d/1VSAiFxDwInzx1-KVCB7XH5ta7t7h0feInFpaPlmYVkM/edit#)

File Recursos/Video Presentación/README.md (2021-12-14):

### Para ver el video presentación final:

- [link](https://www.youtube.com/watch?v=Ris-If8YwiQ)

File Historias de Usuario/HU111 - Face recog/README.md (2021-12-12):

# Reconocimiento facial
Falta acomodar los nombres a los estandares de las otras HU

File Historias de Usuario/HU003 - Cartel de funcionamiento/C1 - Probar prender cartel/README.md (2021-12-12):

# HU03C1

Si estas buscando algo aca 

me tomo la libertad derivarte a  [HU05C3](https://github.com/JuanICasareski/Automatic-Sanitary-Modular-Booth/tree/main/HU005%20-%20Cartel%20de%20ocupado%20y%20buzzer/C3%20-%20Prueba%20Cartel)

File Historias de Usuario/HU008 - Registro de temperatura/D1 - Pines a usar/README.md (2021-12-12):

### Pines lector de tarjetas
4 en total

1 Sda

1 Sck

1 Miso

1 Irq

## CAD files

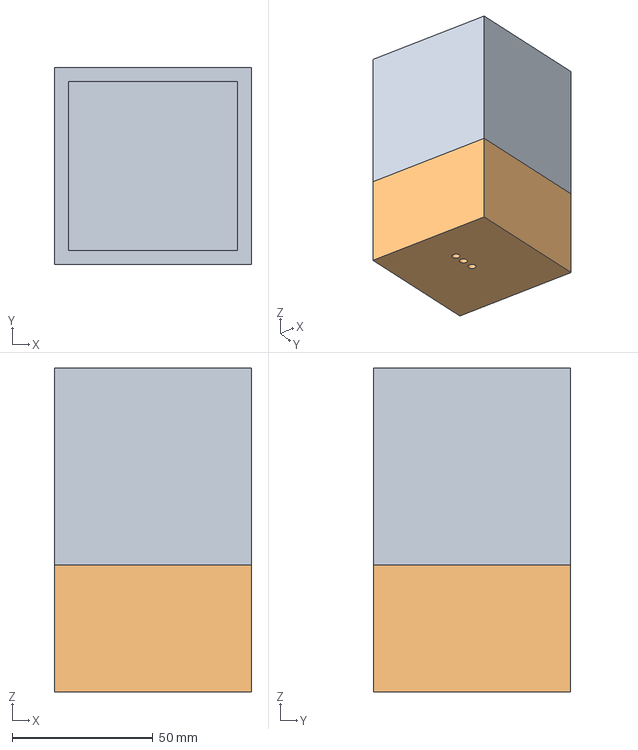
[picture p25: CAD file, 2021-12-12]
Historias de Usuario/HU009 - Dispenser de alcohol/A3 - Modelo 3d/Modelo 3D.iges
70.0 x 70.0 x 115.0 mm

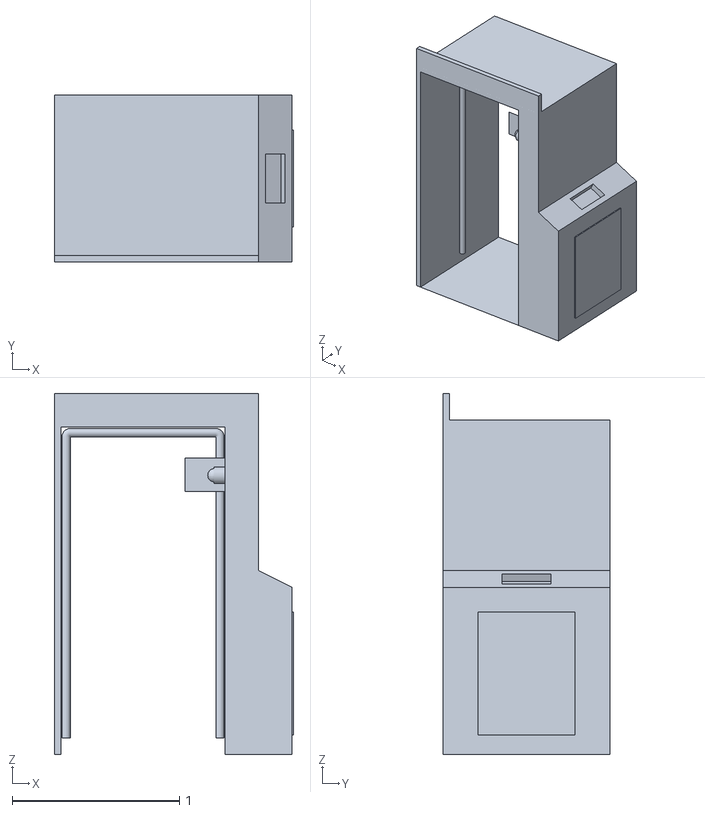
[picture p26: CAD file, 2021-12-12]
Historias de Usuario/Tareas extras/Pasar modelos de blender a autocad/Cabina.dxf
1.43 x 1.00 x 2.16

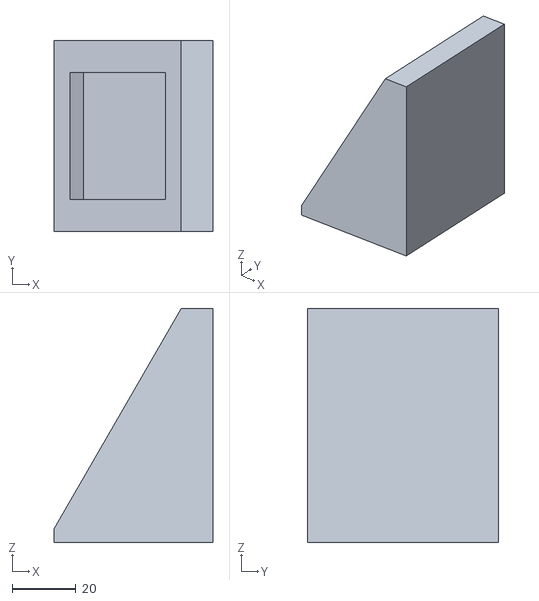
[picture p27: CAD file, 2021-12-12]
Historias de Usuario/HU016 - Check In Empleados/A3 - Modelo 3d/Lector de tarjetas.dxf
50.0 x 60.0 x 73.6

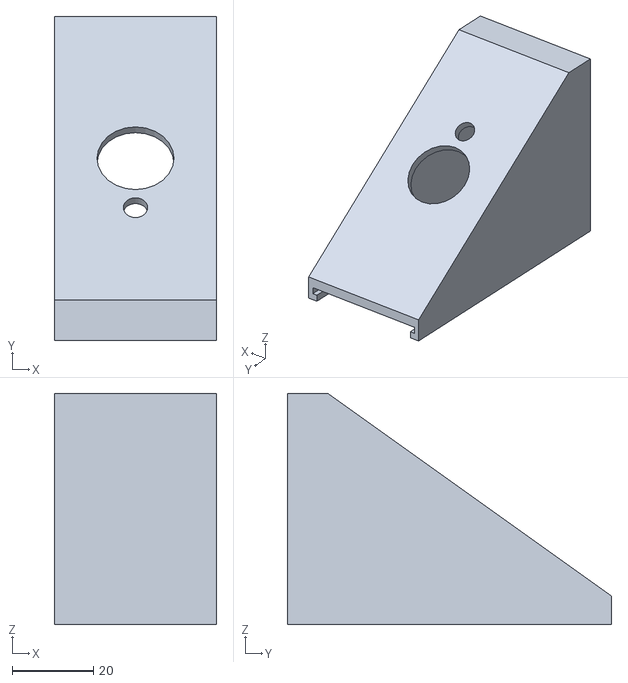
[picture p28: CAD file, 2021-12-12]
Recursos/Modelos/Sensor de temperatura/Caja sensor de temperatura.stl
40.0 x 80.0 x 57.0

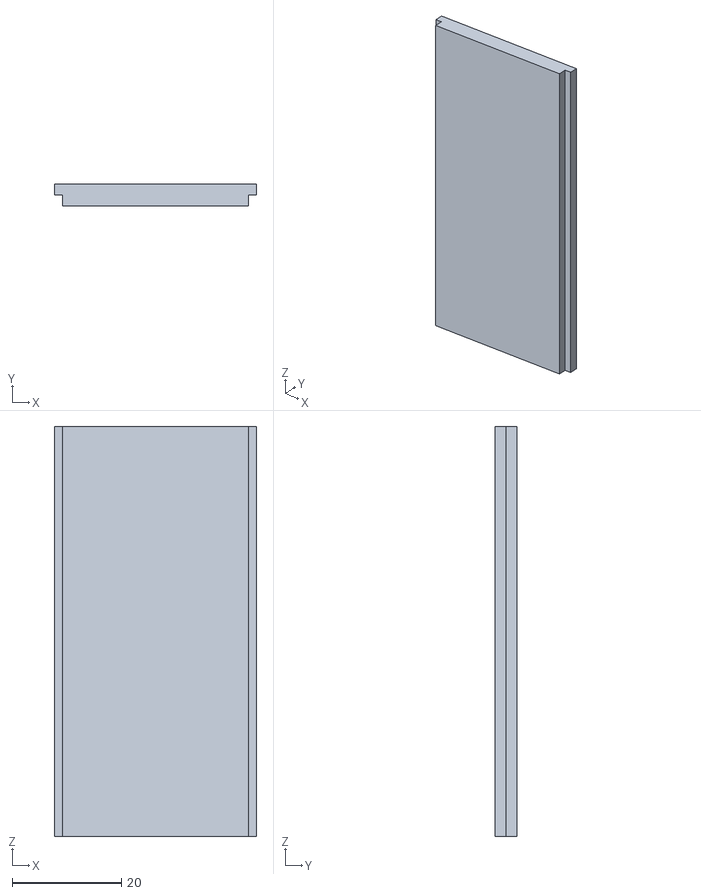
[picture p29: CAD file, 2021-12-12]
Recursos/Modelos/Lector de tarjetas/Tapa lector de tarjetas.stl
37.0 x 4.00 x 75.0

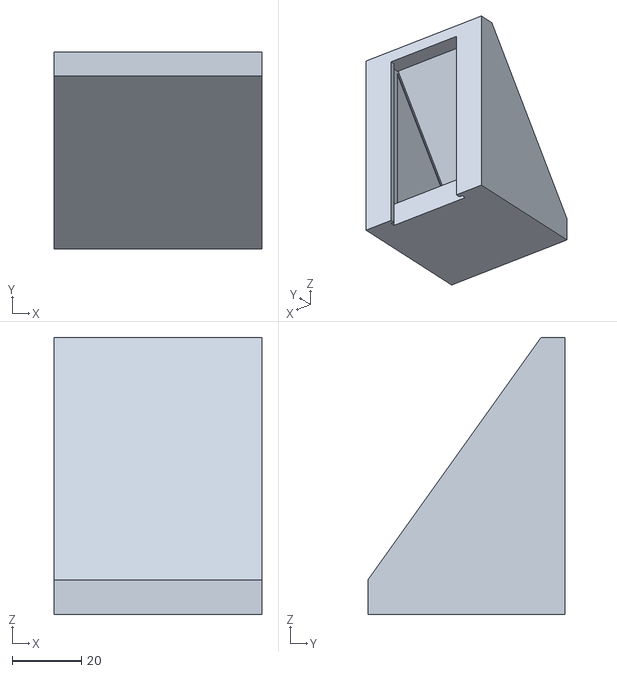
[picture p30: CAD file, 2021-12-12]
Recursos/Modelos/Lector de tarjetas/Caja lector de tarjetas.stl
60.0 x 57.0 x 80.0

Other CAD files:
Recursos/Modelos/Cabina general/Modelo Camara.dwg
Recursos/Modelos/Cartel ocupado/Cartel Ocupado.dwg
Recursos/Modelos/Dispenser de alcohol en gel/Dispenser de alcohol en gel.dwg
Recursos/Modelos/Lector de tarjetas/Lector de tarjetas.dwg
Historias de Usuario/Tareas extras/Pasar modelos de blender a autocad/SuperCabinaSanitizante.stl
Recursos/Modelos/Cabina general/Perfil otro tubo.dwg
Recursos/Modelos/Sensor de temperatura/Sensor de temperatura.dwg
Recursos/Modelos/Cabina general/Perfil tubo.dwg
Recursos/Modelos/Sensor de temperatura/Tapa sensor de temperatura.stl
Recursos/Modelos/Cabina general/Modelo Cabina.dwg
Historias de Usuario/HU009 - Dispenser de alcohol/A3 - Modelo 3d/Modelo 3D.dwg
Historias de Usuario/HU009 - Dispenser de alcohol/A3 - Modelo 3d/Modelo 3D.igs
Historias de Usuario/HU009 - Dispenser de alcohol/A3 - Modelo 3d/Modelo 3D.stl
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

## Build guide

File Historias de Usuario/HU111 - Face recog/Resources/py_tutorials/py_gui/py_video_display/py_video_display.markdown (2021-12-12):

Getting Started with Videos {#tutorial_py_video_display}
===========================

Goal
----

-   Learn to read video, display video, and save video.
-   Learn to capture video from a camera and display it.
-   You will learn these functions : **cv.VideoCapture()**, **cv.VideoWriter()**

Capture Video from Camera
-------------------------

Often, we have to capture live stream with a camera. OpenCV provides a very simple interface to do this.
Let's capture a video from the camera (I am using the built-in webcam on my laptop), convert it into
grayscale video and display it. Just a simple task to get started.

To capture a video, you need to create a **VideoCapture** object. Its argument can be either the
device index or the name of a video file. A device index is just the number to specify which camera.
Normally one camera will be connected (as in my case). So I simply pass 0 (or -1). You can select
the second camera by passing 1 and so on. After that, you can capture frame-by-frame. But at the
end, don't forget to release the capture.
@code{.py}
import numpy as np
import cv2 as cv

cap = cv.VideoCapture(0)
if not cap.isOpened():
    print("Cannot open camera")
    exit()
while True:
    # Capture frame-by-frame
    ret, frame = cap.read()

    # if frame is read correctly ret is True
    if not ret:
        print("Can't receive frame (stream end?). Exiting ...")
        break
    # Our operations on the frame come here
    gray = cv.cvtColor(frame, cv.COLOR_BGR2GRAY)
    # Display the resulting frame
    cv.imshow('frame', gray)
    if cv.waitKey(1) == ord('q'):
        break

# When everything done, release the capture
cap.release()
cv.destroyAllWindows()@endcode
`cap.read()` returns a bool (`True`/`False`). If the frame is read correctly, it will be `True`. So you can
check for the end of the video by checking this returned value.

Sometimes, cap may not have initialized the capture. In that case, this code shows an error. You can
check whether it is initialized or not by the method **cap.isOpened()**. If it is `True`, OK.
Otherwise open it using **cap.open()**.

You can also access some of the features of this video using **cap.get(propId)** method where propId
is a number from 0 to 18. Each number denotes a property of the video (if it is applicable to that
video). Full details can be seen here: cv::VideoCapture::get().
Some of these values can be modified using **cap.set(propId, value)**. Value is the new value you
want.

For example, I can check the frame width and height by `cap.get(cv.CAP_PROP_FRAME_WIDTH)` and `cap.get(cv.CAP_PROP_FRAME_HEIGHT)`. It gives me
640x480 by default. But I want to modify it to 320x240. Just use `ret = cap.set(cv.CAP_PROP_FRAME_WIDTH,320)` and
`ret = cap.set(cv.CAP_PROP_FRAME_HEIGHT,240)`.

@note If you are getting an error, make sure your camera is working fine using any other camera application
(like Cheese in Linux).

Playing Video from file
-----------------------

Playing video from file is the same as capturing it from camera, just change the camera index to a video file name. Also while
displaying the frame, use appropriate time for `cv.waitKey()`. If it is too less, video will be very
fast and if it is too high, video will be slow (Well, that is how you can display videos in slow
motion). 25 milliseconds will be OK in normal cases.
@code{.py}
import numpy as np
import cv2 as cv

cap = cv.VideoCapture('vtest.avi')

while cap.isOpened():
    ret, frame = cap.read()

    # if frame is read correctly ret is True
    if not ret:
        print("Can't receive frame (stream end?). Exiting ...")
        break
    gray = cv.cvtColor(frame, cv.COLOR_BGR2GRAY)

    cv.imshow('frame', gray)
    if cv.waitKey(1) == ord('q'):
        break

cap.release()
cv.destroyAllWindows()
@endcode

@note Make sure a proper version of ffmpeg or gstreamer is installed. Sometimes it is a headache to
work with video capture, mostly due to wrong installation of ffmpeg/gstreamer.

Saving a Video
--------------

So we capture a video and process it frame-by-frame, and we want to save that video. For images, it is
very simple: just use `cv.imwrite()`. Here, a little more work is required.

This time we create a **VideoWriter** object. We should specify the output file name (eg:
output.avi). Then we should specify the **FourCC** code (details in next paragraph). Then number of
frames per second (fps) and frame size should be passed. And the last one is the **isColor** flag. If it is
`True`, the encoder expect color frame, otherwise it works with grayscale frame.

[FourCC](http://en.wikipedia.org/wiki/FourCC) is a 4-byte code used to specify the video codec. The
list of available codes can be found in [fourcc.org](http://www.fourcc.org/codecs.php). It is
platform dependent. The following codecs work fine for me.

-   In Fedora: DIVX, XVID, MJPG, X264, WMV1, WMV2. (XVID is more preferable. MJPG results in high
    size video. X264 gives very small size video)
-   In Windows: DIVX (More to be tested and added)
-   In OSX: MJPG (.mp4), DIVX (.avi), X264 (.mkv).

FourCC code is passed as `cv.VideoWriter_fourcc('M','J','P','G')` or
`cv.VideoWriter_fourcc(*'MJPG')` for MJPG.

The below code captures from a camera, flips every frame in the vertical direction, and saves the video.
@code{.py}
import numpy as np
import cv2 as cv

cap = cv.VideoCapture(0)

# Define the codec and create VideoWriter object
fourcc = cv.VideoWriter_fourcc(*'XVID')
out = cv.VideoWriter('output.avi', fourcc, 20.0, (640,  480))

while cap.isOpened():
    ret, frame = cap.read()
    if not ret:
        print("Can't receive frame (stream end?). Exiting ...")
        break
    frame = cv.flip(frame, 0)

    # write the flipped frame
    out.write(frame)

    cv.imshow('frame', frame)
    if cv.waitKey(1) == ord('q'):
        break

# Release everything if job is finished
cap.release()
out.release()
cv.destroyAllWindows()
@endcode

Additional Resources
--------------------

Exercises
---------

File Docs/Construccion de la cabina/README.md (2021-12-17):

# Construcción de la estructura de la cabina

Los materiales usados para la construccion de la cabina fueron reciclados de proyectos abandonados que habia en la escuela, de uno de ellos sacamos los caños cuadrados de metal de 4x6cm x 3mm de espesor. A continuacion, fotos del mismo

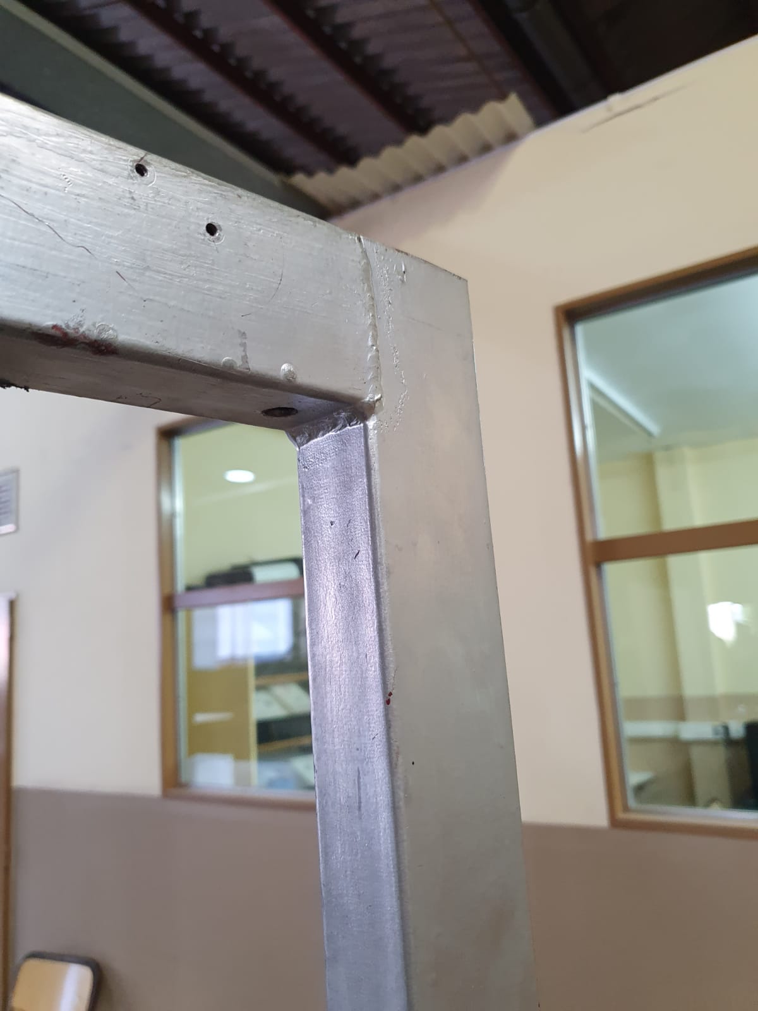
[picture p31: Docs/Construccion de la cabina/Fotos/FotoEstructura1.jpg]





Todo este marco fue cortado utilizando una moladora



Y una vez cortado en partes mas trasnportables los llevamos a aeronautica para cortarlos de forma mas precisa con la moladora de banco



Luego se emprolijaron los bordes utilizando la moladora con discos flappers



Una vez emprolijadas las superficies pasamos soldar, proceso el cual al principio fue complicado porque ninguno sabia como soldar. De todas formas dimos nuestro mejor intento y conseguimos lo siguiente

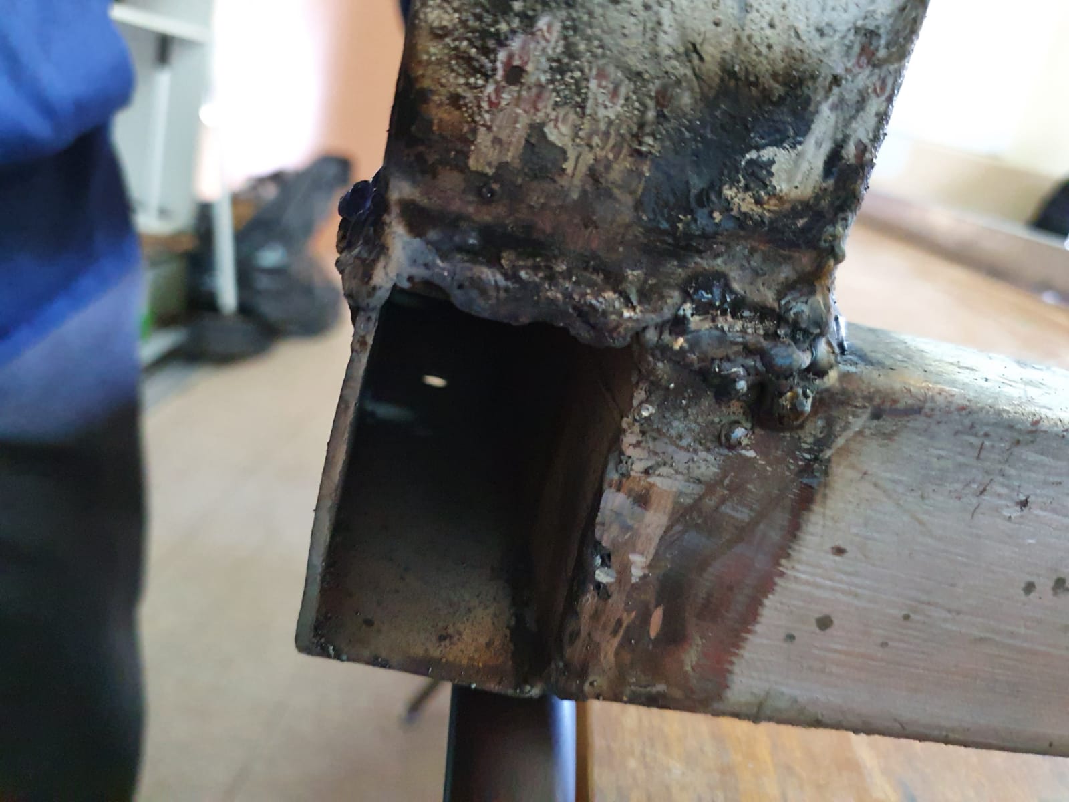
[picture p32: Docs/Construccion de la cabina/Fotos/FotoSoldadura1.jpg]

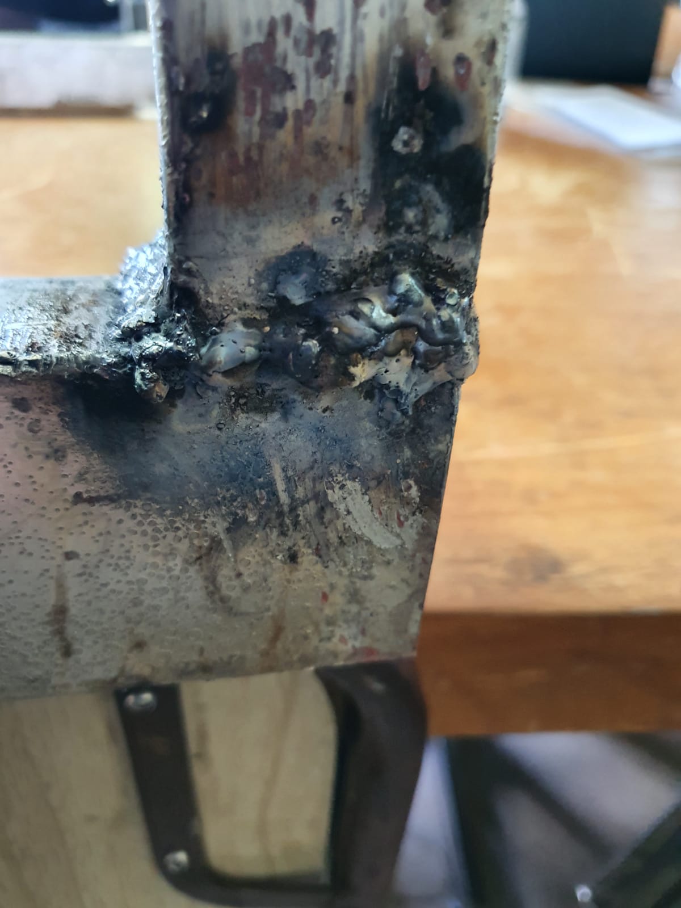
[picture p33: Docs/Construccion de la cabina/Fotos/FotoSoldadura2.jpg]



Estas no eran resistentes y se terminaron rompiendo, esto nos llevo a realizar practicas de soldadura con la ayuda las indicaciones de los profesore. A continuacion un ejemplo:

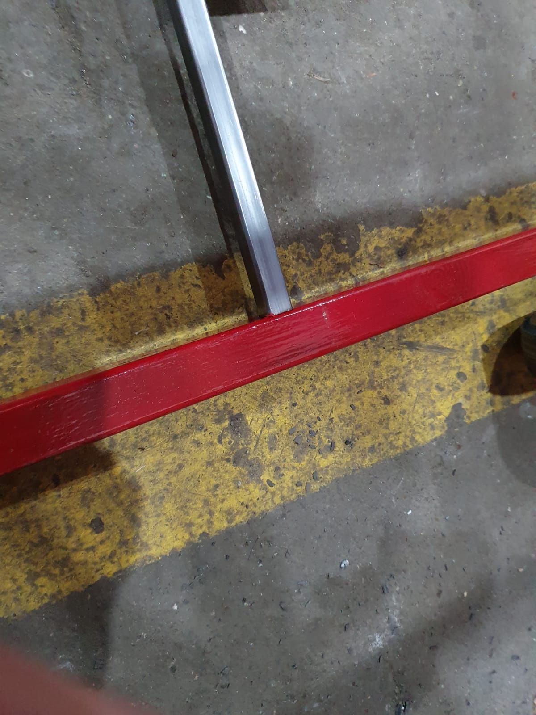
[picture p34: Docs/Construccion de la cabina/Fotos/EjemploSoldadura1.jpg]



Ya con estas practicas, las soldaduras posteriores se realizaron adecuadamente y eran resistentes, lo siguiente a realizar fue rebajarlas para emprolijarlas al resto de los perfiles



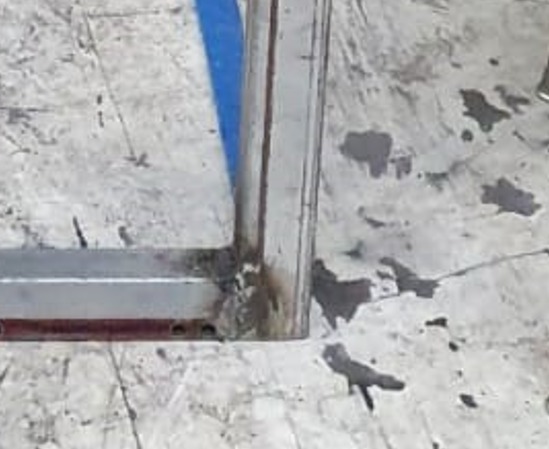
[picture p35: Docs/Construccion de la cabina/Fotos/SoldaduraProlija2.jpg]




En este punto se dio por finalizada la construccion de la base de la cabina



El siguiente paso fue construir el panel de estado, en este utilizamos tambien materiales reciclados, entre los que se incluyen perfiles en U cuadrados; de tamaño grande y chico; y muchos remaches

Primera medimos y cortamos con la moladora, agujereamos y remachamos unos con otros hasta terminarlos


>Ignorar las exageradas medidas de seguridad

Por ultimo la remachamos la base y finalizamos la estructura de la cabina

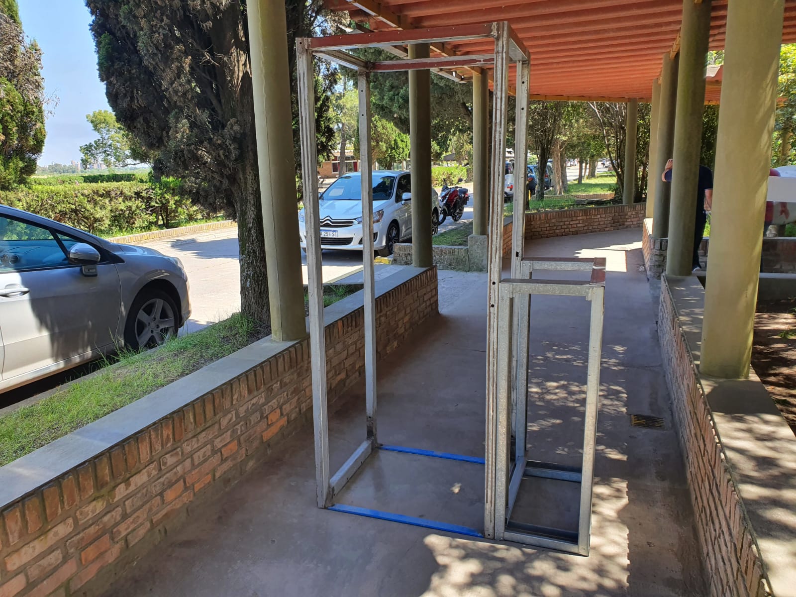
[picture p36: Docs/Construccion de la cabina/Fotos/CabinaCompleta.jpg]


La siguien etapa de la construccion fue la colocacion de los paneles y perfiles de pvc a modo de pared los cuales fueron cortados con cierra, con moladora, emprolijados con un dremel con una herramienta de piedra de devaste y unidos a la estructura encastrandose unos con otros y luego en los bordes J, estos ultimos amurados con remaches a la cabina



Luego de esto nos dimos cuenta que el panel de estado necesitaria diferentes niveles para colocar la electronica, en total tres, uno para la bomba de agua y su tanque, y otras dos para la electronica. 

Esto nos llevo a diseñar unas pequeñas ventanas para luego soldar caños cuadrados en U que servirian de soporte para una plancha donde iria la electronica, estas ventanas fueron cortadas con sierra y moladora.

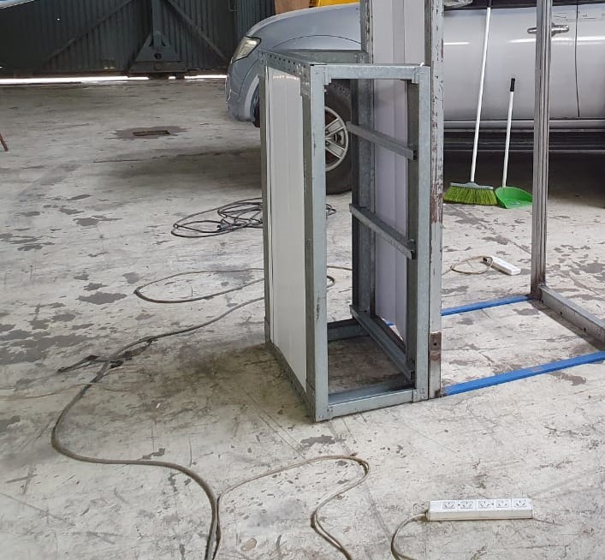
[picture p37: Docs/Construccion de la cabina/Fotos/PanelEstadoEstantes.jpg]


Una vez terminado notamos que entraban a presion y quedaban bien sujetas, teniendo en cuenta el peso que tendria que soportar los estantes y las dificultades ambientales que podria experimentar (vibraciones, vientos fuertes, inclinaciones, etc), determinamos que era suficiente y no necesitaba soldar.
Luego colocamos las planchas, el material elegido fue el carton. Realizamos algunos agujeros y pasamos los cables

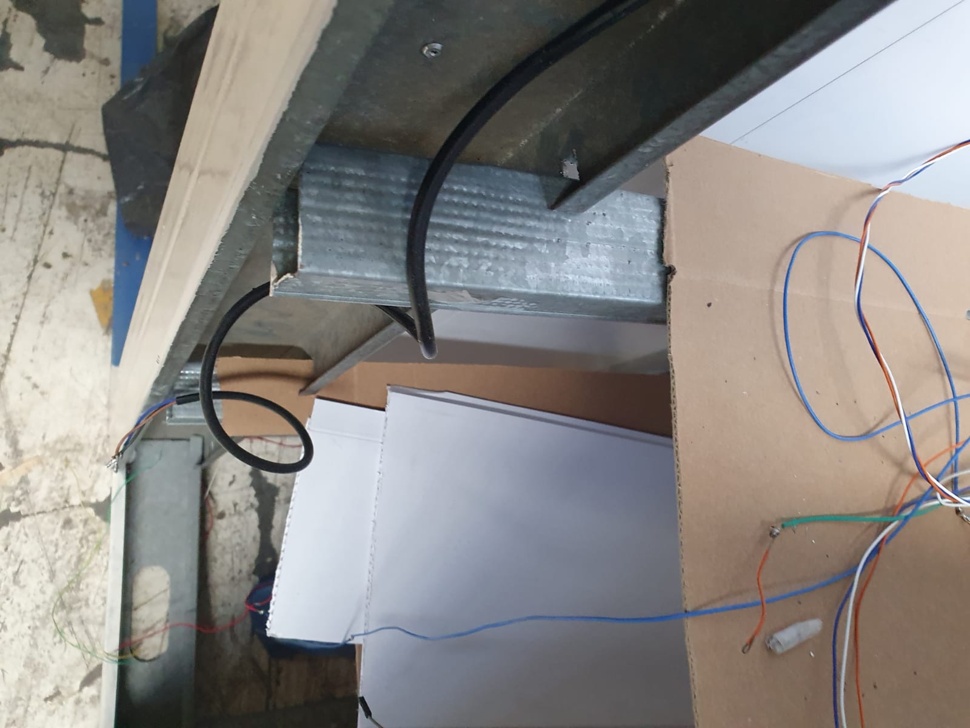
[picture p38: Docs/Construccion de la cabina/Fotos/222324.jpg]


Luego pusimos manos a la obra y pintamos la cabina con pintura antioxidante blanca, fueron exactamente 3 capas de pintura.

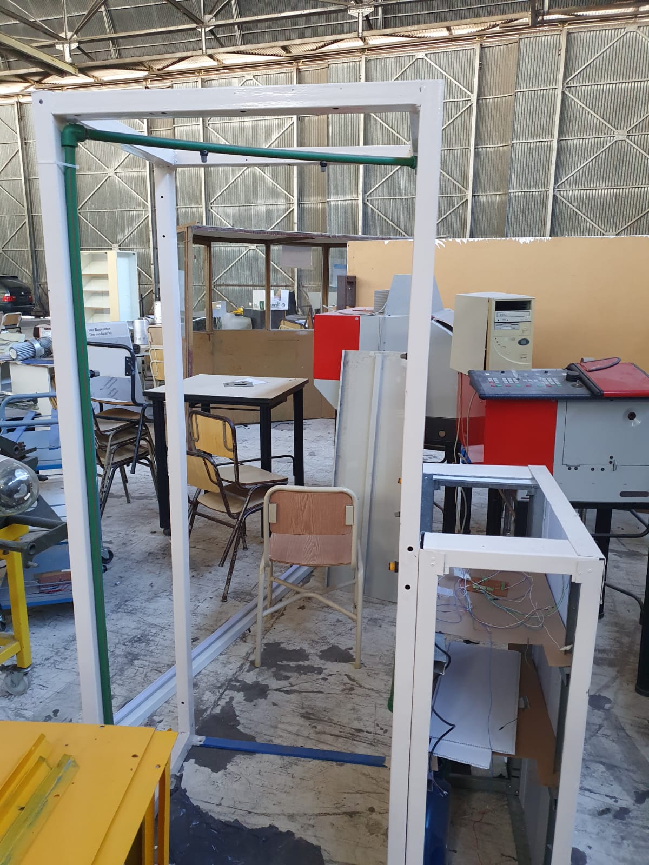
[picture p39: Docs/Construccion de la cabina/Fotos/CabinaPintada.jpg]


En esta foto tambien podemos ver el sistema de desinfeccion acoplado en la cabina, ese se construyo utilizando tubos de termofusion de agua (de 1/2), 3 uniones de codo, un tapon, 6 aspersores, la bomba de agua, tanque de liquido desinfectante y sus adaptadores y conectores. los caños y las uniones las teniamos planeado unir con termofusora, pero debido a un problema con esta (y el hecho de que necesitabamos terminarla) decidimos unirlas a presion y utilizar sellador para cerrar posibles fugas.
Luego realizamos perforacion, en total 6, sobre la extencion de los caños para ubicar los aspersores, estos tambien fueron unidos a presion y con sellador. Por ultimo unimos los caños a la estructura utilizando precintos.




Para el lado de la pared tuvimos que sacar una de las placas, cortar para hacer una ventana para los caños, colocarla denuevo y recien alli, pasar los caños

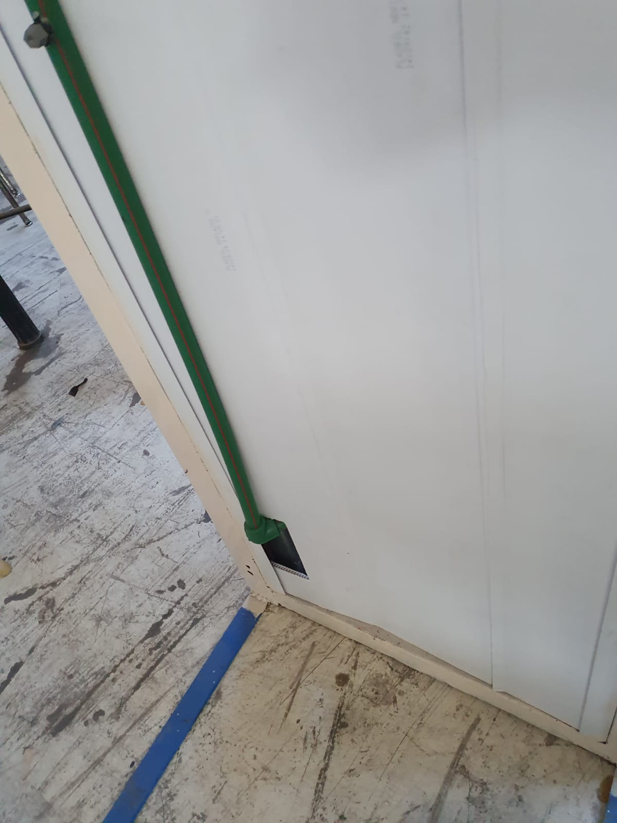
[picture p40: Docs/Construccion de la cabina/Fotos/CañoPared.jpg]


De este ultimo llegamos a la bomba de agua, la cual esta conectado al tanque y se encarga de bombear el liquido sanitizante, estos estan unido mediante adaptadores de rosca, y en el caso del tanque mediante un tapon hecho a base de cinta y sellador.

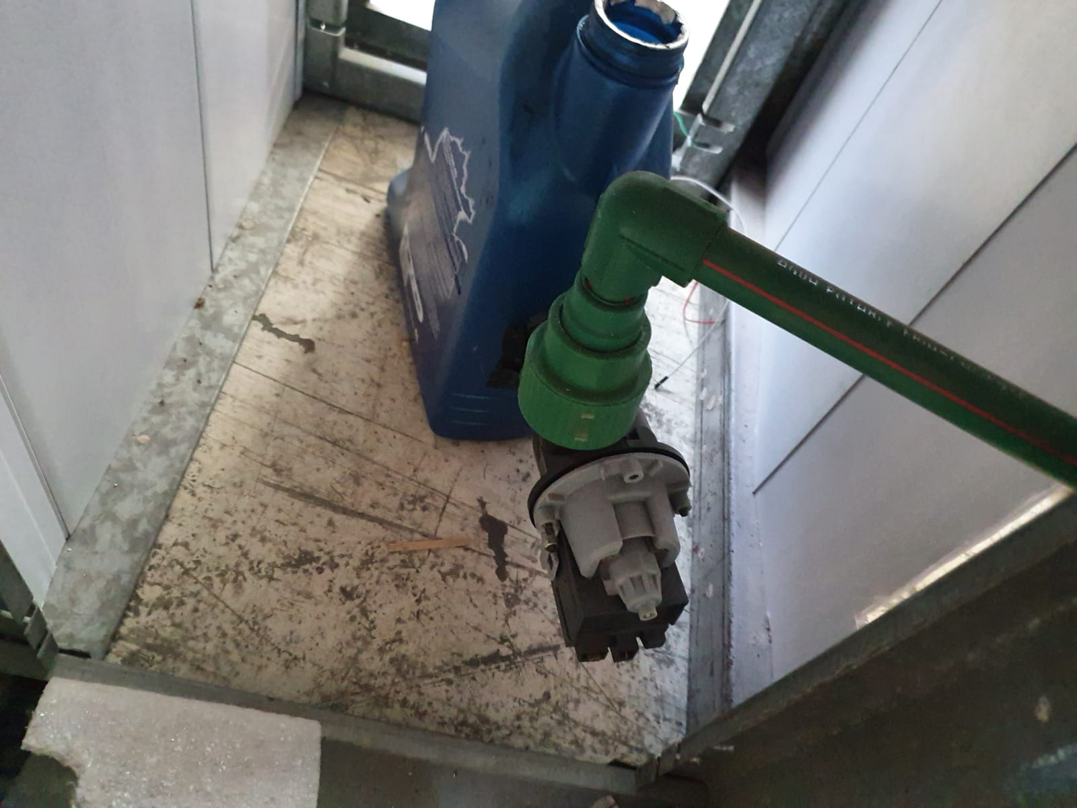
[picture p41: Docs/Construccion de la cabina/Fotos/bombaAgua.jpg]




Con esto ultimo dariamos por finalizada la documentacion del proceso de construccion de la cabina, muchas gracias por leer. Una ultima foto de la cabina:



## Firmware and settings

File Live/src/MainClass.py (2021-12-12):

import adafruit_mlx90614 as mlx90614
import RPi.GPIO as GPIO
import busio as io
import board
from imutils.video import VideoStream
from Libs.DetectMask import detectMask
from Libs.simpleRC522 import SimpleMFRC522
from Libs.SQLFunctions import logSensors, logEmployee
from Libs.DetectEyesMouth import detectClosedEyesAndMouth

from time import sleep


enUso:bool = False
enFuncionamiento:bool = True

#GPIO.setmode(GPIO.BOARD)

def setUso(v:bool):
    global enUso
    enUso = v
def setFuncionamiento(v:bool):
    global enFuncionamiento
    enFuncionamiento = v
def getFuncionamiento():
    return enFuncionamiento
def getUso():
    return enUso

class ASMB:
    def __init__(self, ) -> None:
        '''Clase general de la cabina'''
        pass
    class Pin:
        def __init__(self, pin, mode=GPIO.OUT, state=0) -> None:
            '''Constructor para los pines'''
            self.__pin = pin
            self.__modes = {'output':GPIO.OUT, 'input':GPIO.IN}
            self.__mode = mode
            self.__state = state 
            GPIO.setup(self.__pin, self.__modes[mode])
      
        def toggleState(self) -> None:
            '''Alterna el estado del pin'''
            if self.__mode == 'output':
                GPIO.output(self.__pin, not self.__state)
                self.__state = not self.__state
            else:
                raise Exception(f'Modo del pin {self.__pin}:{self.__mode}')

        def setState(self, state) -> None:
            '''Cambia el estado del pin'''
            if self.__state != state:
                if self.__mode == 'output':
                    GPIO.output(self.__pin, state)
                    self.__state = state
                else:
                    raise Exception(f'Modo del pin {self.__pin}:{self.__mode}')

        def getState(self) -> bool:
            '''Devuelve el estado del pin'''
            if self.__mode == 'input':
                state = GPIO.input(self.__pin)
                return bool(state)
            raise Exception(f'Modo del pin {self.__pin}:{self.__mode}')

        def push(self, state):
            if self.__mode == 'output':
                    GPIO.output(self.__pin, state)
                    GPIO.output(self.__pin, not state)
            else:
                raise Exception(f'Modo del pin {self.__pin}:{self.__mode}')

    class IO:       # Revisar nombre
        def __init__(self, entrada, salida, led) -> None:
            '''Constructor para los sensores de entrada y salida'''
            self.__entrada:ASMB.Pin = entrada
            self.__salida:ASMB.Pin = salida
            self.__led:ASMB.Pin = led

        def checkEntry(self,) -> None:
            ''''Verifica la entrada de un usuario'''
            while 1:
                e = self.__entrada.getState()
                if e:
                    setUso(True)
                    break
                self.__led.setState(0)
                sleep(0.1)

        def checkExit(self,) -> None:
            '''Verifica la salida del usuario'''
            while 1:
                e = self.__salida.getState()
                if e:
                    setUso(False)
                    break
                self.__led.setState(1)
                sleep(0.1)

    class CartelFuncionamiento:     # Revisar nombre
        def __init__(self, pin) -> None:
            '''Constructor para el cartel de funcionamiento'''
            self.__pin:ASMB.Pin = pin
        def setState(self, state) -> None:
            '''Cambia el estado del cartel de funcionamiento'''
            print(f'getFuncionamiento()={getFuncionamiento()}')
            if getFuncionamiento() != state:
                self.__pin.setState(state)
                setFuncionamiento(bool(state))

    class Temperatura:      # Revisar nombre
        def __init__(self, freq=100e3) -> None:
            '''Constructor para el mlx90614'''
            self.__i2c = io.I2C(board.SCL, board.SDA, frequency=freq)
            self.__mlx = mlx90614.MLX90614(self.__i2c)
        def readTemp(self,) -> list:
            '''Lee la temperatura en un intervalo de 25s maximos, de ser valida devuelve (True, temp) y en caso contrario (False, temp)'''
            mlx = self.__mlx
            while 1:
                temp = mlx.object_temperature
                if temp>=28:
                    break
            for _ in range(101):
                temp = mlx.object_temperature
                if 36<=temp<=37:
                    return True, temp 
                sleep(0.25)
            return False, temp
            
    class PanelEstado:
        def __init__(self, testPin, sh_cp, ds, st_cp, pinEntrada, pinAlcohol, pinSalida) -> None:
            '''Constructor para el panel de estado'''
            self.testPin:ASMB.Pin = testPin
            self.sh_cp:ASMB.Pin = sh_cp
            self.ds:ASMB.Pin = ds
            self.st_cp:ASMB.Pin = st_cp

            self.pinEntrada:ASMB.Pin = pinEntrada
            self.pinAlcohol:ASMB.Pin = pinAlcohol
            self.pinSalida:ASMB.Pin = pinSalida
            
        def logSensors(self, states:tuple) -> None:
            '''Envia los estados de los sensores al panel de estado'''
            registerRefreshPin = self.sh_cp
            serialOut = self.ds
            outputRefreshPin = self.st_cp
            for e in states:    
                serialOut.setState(e)
                registerRefreshPin.push(1)
            outputRefreshPin.push(1)
            logSensors(states) # No, no se llama a si misma. Es una funcion de otro lugar

        def getSensorStatus(self,) -> list:
            estados = [False]*8
            '''[temperatura, tarjetas, entrada, alcohol, salida, ?, ?, cam]'''
            try:
                i2c = io.I2C(board.SCL, board.SDA, frequency=100e3)
                mlx90614.MLX90614(i2c)
                estados[0] = False
            except:     # Poner la excepcion posta
                estados[0] = True

            try:
                SimpleMFRC522(busa=0, devicea=0)
                estados[1] = False
            except:     # Poner la excepcion posta
                estados[1] = True

            estados[2] = self.pinEntrada.getState()
            estados[3] = self.pinAlcohol.getState()
            estados[4] = self.pinSalida.getState()

            estados[5] = False      # Alto placeholder
            estados[6] = False      # x2

            try:
                VideoStream(src=0).start().stop()
                estados[0] = False
            except:     # Poner la excepcion posta
                estados[7] = True

            return estados
    
    class DispenserAlcohol:
        def __init__(self, pinSensor, pinMotor, tiempoDeActivacion):
            '''Constructor del dispenser de alcohol'''
            self.__timer = tiempoDeActivacion
            self.__pinSensor:ASMB.Pin = pinSensor
            self.__pinMotor:ASMB.Pin = pinMotor
        def dispensar(self,):
            self.__pinMotor.setState(1)
            sleep(self.__timer)
            self.__pinMotor.setState(0)
        def verMano(self,):        # Revisar nombre 
            while 1:                
                if self.__pinSensor.getState():
                    self.dispensar()
                sleep(.1)

    class LectorDeTarjetas:
        def __init__(self, bus=0, device=0):
            self.__reader = SimpleMFRC522(bus, device)
        def readCard(self):
            while 1:
                id, text = self.__reader.read()
                return id, text

    class FaceDetection:
        def __init__(self, mode:str='eyes&Mouth'):
            '''
                modes:
                    - 'eyes&Mouth', detecta los ojos y boca cerrados por 3 segs
                    - 'mask', detecta el uso de un barbijo por 3 segs
            '''
            self.__mode = mode
        def detect(self):
            if self.__mode=='eyes&Mouth':
                detectClosedEyesAndMouth()
            elif self.__mode=='mask':
                detectMask()
            else:
                raise Exception("Los modos puede ser 'eyes&Mouth' || 'mask'")
            return 

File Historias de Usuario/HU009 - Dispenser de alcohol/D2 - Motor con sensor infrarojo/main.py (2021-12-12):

from time import sleep
import RPi.GPIO as GPIO

GPIO.setmode(GPIO.BOARD)
GPIO.setup(8, GPIO.OUT)
GPIO.setup(10, GPIO.IN)

lastState = 0

while 1:
    currentState = GPIO.input(10)

    if currentState!=lastState:
        if currentState:
            GPIO.output(8, GPIO.HIGH)
            sleep(2)
            GPIO.output(8, GPIO.LOW)
        lastState = currentState

    sleep(0.1)

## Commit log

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2021-05-23 Terminé HU08C1 y uní las dos libs de SQL
2021-05-23 Creé TODO en libs y eliminé una linea de prueba en HU08
2021-05-25 Agregúe HU016A1, A2 y A3
    [Lector de tarjetas.dwg, Lector de tarjetas.dxf]
2021-05-25 Actualizé HU016A1, A2 Y A3
    [Lector de tarjetas.dwg, Lector de tarjetas.dxf]
2021-05-25 Agregué HU09A1, A2 Y A3
    [Modelo 3D.dwg, Modelo 3D.iges, Modelo 3D.igs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]
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2021-05-29 Corregi un error con algunas funciones de SQL
    [SQLFunctions.py]
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2021-06-01 Corregi error de estado de la libreria
    [Indicadores.py]
2021-06-01 Agregué tareas extras
    [Cabina.dxf, SuperCabinaSanitizante.blend, SuperCabinaSanitizante.obj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]
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2021-06-03 Renamed Extras to Tareas extras
    [Cabina.dxf, SuperCabinaSanitizante.blend, SuperCabinaSanitizante.obj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]
2021-06-03 Agregué recursos varios
    [Lector de tarjetas.dwg, Lector de tarjetas.dxf, Modelo 3D.dwg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]
2021-06-03 Actualizé algunos modelos y agregúe otros
    [Cabina sanitizante.blend, Dispenser de alcohol en gel.blend, Modelo 3D.dwg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]
2021-06-03 Eliminé carpeta duplicada
    [Cabina.dxf, SuperCabinaSanitizante.blend, SuperCabinaSanitizante.obj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]
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2021-06-08 Borré PRIMARY KEY de mas
    [Cartel Ocupado.dwg]
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2021-06-09 Arreglé falta de primary key
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2021-08-07 Agregué el link de la carpeta de campo
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2021-08-22 Agregué el circuito de los sensores de proximidad
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2021-09-26 Fix: Corregir footprint y tamaño del pcb
2021-09-26 Fix: Corregir GND
2021-10-01 Fix: Reacomodar footprints
2021-10-07 Feat: Modelado
    [Sensor Modelado.dwg]
2021-10-10 Feat: Crear perfil de los tubos
    [Perfil tubo.dwg]
2021-10-10 Feat: Crear modelo de la parte principal
    [Modelo Cabina.dwg]
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2021-10-11 Feat: Crear perfil de los tubos del pane de estado
    [Perfil otro tubo.dwg]
2021-10-11 Feat: Crear modelo 3d del panel de estado
    [Modelo Cabina.dwg]
2021-10-11 Refact: Creo Modelo
    [perfi_llector_de_tarjetas.dwg]
2021-10-18 Feat: Crear modelo del soprote de la camara
    [camara.dwg]
2021-11-02 Feat: Agregar el modelo del soporte de la camara
    [Modelo Cabina.dwg]
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2021-11-04 Fix: Cambiar importacion de bootstrap
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2021-11-06 Fix: corregir formato de entradas.html
2021-11-07 Fix: COrregir uso de imagen
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2021-11-07 Fix: Invertir color de sombreado
2021-11-08 Feat: Crear panel de control con las ultimas entradas
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2021-11-09 Feat: Implementar cambios de admins en el index
2021-11-10 Fix: Corregir formato de bloques
    [SQLFunctions.py, main.py]
2021-11-10 Feat: Crear datos de ejemplos para cambios de admins
2021-11-10 Fix: Eliminar h1 extra y corregir dir de imagen
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2021-11-13 Fix: Corregir url para iconos
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2021-11-13 Feat: Transformar pagina de empleado a una con sus datos
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2021-11-13 Fix: url para iconos
2021-11-13 Feat: Crear Url para entradas recientes de un empleado
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2021-11-13 Feat: Agregar boton apra agregar a la watchlist
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2021-11-14 Feat: Crear funcción para conseguir estados de las cabinas
2021-11-14 Fix: Corregir función que devuelve el ultimo estaod de cada cabina
    [SQLFunctions.py]
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2021-11-14 Feat: Crear página para ver estados de cabinas
2021-11-14 Feat: Convertir lista en str a su correcto formato
    [main.py]
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2021-11-15 Feat: Crear base para sistema de login y logout
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2021-11-15 Style: Asutar nombre de variables para el login
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2021-11-15 Fix: Corregir variable con nombre equivoco
    [main.py]
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2021-11-15 Fix: Función de checkeo de empleado
    Antes solo verificaba si el nombre se repetia
    [SQLFunctions.py]
2021-11-15 Fix: Corregir uso de las comillas
    [SQLFunctions.py]
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2021-11-15 Fix: Corregir nombre de columnas
    [SQLFunctions.py]
2021-11-15 Feat: Hacer que si un empleado ya estÃá creado redireccione a su pagina
2021-11-15 Feat: Implementar poder sacar y poner empleados en la watchlist
2021-11-16 Feat: Agregar pagina para ver ultimo estado de cabina
2021-11-17 Feat: Comunicación por socket para cargar entradas y otros a la DB
2021-11-17 Fix: Corregir padding incorrecto entre empleados en la watchlist
2021-11-17 Fix: Insertar correctamente nombre de admin en watchlistIO
    [SQLFunctions.py]
2021-11-17 Fix: Ordenar cabinas por id de cabina
    [SQLFunctions.py]
2021-11-17 Style: Dar estilo a la pagina de estado de una cabina
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2021-11-17 Feat: Dar url al boton de estaod recientes
2021-11-17 Style: Centrar tabla de estados recientes de cabina
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2021-11-17 Fix: Corregir log de nombre de empleado
    [main.py]
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2021-11-18 Fix: Cambiar nombre de templates en el main
    [main.py]
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2021-11-19 Fix: Sacar n de cabina
    [SQLFunctions.py, main.py]
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2021-11-19 Fix: Cambiar de watlist segun admin actual
    [main.py]
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2021-11-19 Fix: Decomentar lineas necesarias
    [main.py]
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2021-11-21 Fix: Cambiar ip fija a ip de la pc actual
2021-11-21 Fix: Ordenar cabinas actuales por dia y hora
    [SQLFunctions.py]
2021-12-10 Chore: Ordenar historias de usuario
    [Cabina.dxf, Lector de tarjetas.dwg, Lector de tarjetas.dxf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]
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2021-12-10 Chore: Mover seccin de recursos
    [Cabina sanitizante.blend, Cartel Ocupado.dwg, Dispenser de alcohol en gel.blend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]
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2021-12-10 Chore: Corregir nombre de modelo de la camara
    [Modelo Camara.dwg]
2021-12-10 Chore: Acomodar dir para modelo de la cabina
    [Modelo Cabina.dwg, Modelo Camara.dwg, Perfil otro tubo.dwg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]
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2021-12-11 Chore: Acomodar dir para el modelo del dispenser
    [Dispenser de alcohol en gel.dwg]
2021-12-11 Style: Renombrar modelos del sensor de temperatura
    [Caja sensor de temperatura.stl, Sensor de temperatura.dwg, Tapa sensor de temperatura.stl]
2021-12-11 Chore: Acomodar dir para modelos del sensor de temperatura
    [Caja sensor de temperatura.stl, Sensor de temperatura.dwg, Tapa sensor de temperatura.stl]
2021-12-11 Style: Renombrar modelo del lector de tarjetas
    [Lector de tarjetas.dwg]
2021-12-11 Chore: Acomodar dir para modelo del lector de tarjetas
    [Lector de tarjetas.dwg]
2021-12-11 Fix: Eliminar-Blink-led.py
2021-12-11 Fix: Correxion Lectoctor de Tarjetas
    [perfi_llector_de_tarjetas.dwg]
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2021-12-12 Revert: Remover Carpeta de Recursos
2021-12-12 Docs: Agregae STL's
    [perfi_llector_de_tarjetas caja.stl, perfi_llector_de_tarjetas tapa.stl]
2021-12-12 Fix: Agregar .bak
    [Lector de tarjetas.dwg]
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2021-12-12 Style: Renombrar stl para LEctor de tarjetas
    [Caja lector de tarjetas.stl, Tapa lector de tarjetas.stl]
2021-12-12 Chore: Acomodar dir para modelos del lector de tarjetas
    [Caja lector de tarjetas.stl, Lector de tarjetas.dwg, Tapa lector de tarjetas.stl]
2021-12-12 Hotfix: Actualizar aarchivos para merge
    [Caja lector de tarjetas.stl, Lector de tarjetas.dwg, Tapa lector de tarjetas.stl]
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2021-12-13 Style: Corregir nombre del modelo del lector de tarjetas
    [Caja lector de tarjetas.stl, Lector de tarjetas.dwg, Tapa lector de tarjetas.stl]
2021-12-13 Chore: Eliminar modelo anterior
    [Cabina sanitizante.blend]
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2021-12-16 Docs: Agregar imagenes de los modelos usados en la carpeta de campo
2021-12-16 Docs: Añadir imagenes de los diagramas e icono usados en la carpeta de campo
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2021-12-16 Docs: Agregar imagenes de los pcbs usados en la carpeta de campo
2021-12-16 Refactor: Renombrar la carpeta tecnica para que se muestre en el git
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2021-12-16 Fix: Corregir mayusculas problematicas para la visualizacion del readme
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
